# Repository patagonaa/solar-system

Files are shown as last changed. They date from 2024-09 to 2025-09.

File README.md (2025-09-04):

# Solar System

Build thread (german) at https://chaos.social/@patagona/113149877881417810

## Overview

This is sort-of build log / lessons learned of my off-grid solar system / battery backup.

Specs/Features:
- ~7.2kWh battery
- \>5kW AC out
- 5kW PV in
- 2kW AC in (with configurable power limit)

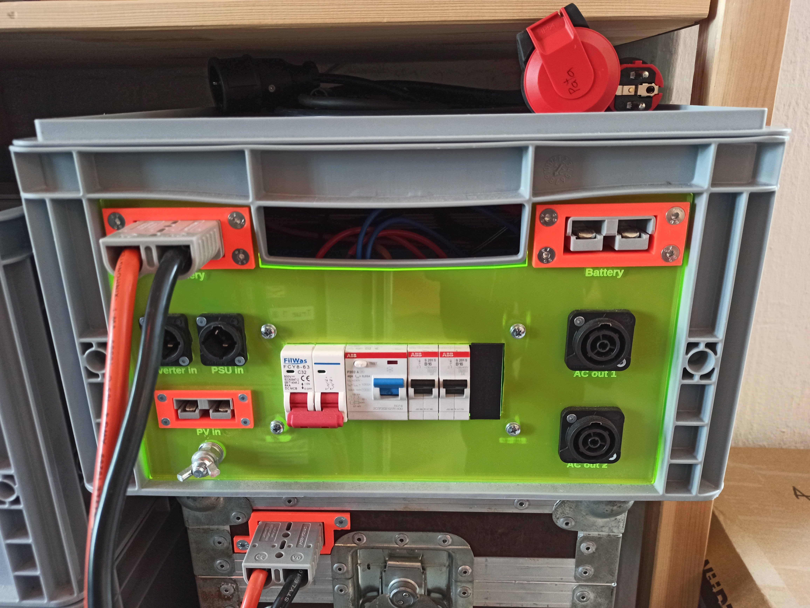
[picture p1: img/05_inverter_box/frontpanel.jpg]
Photo of the laser-cut frontpanel on the side of the euro container with all of the connectors fitted


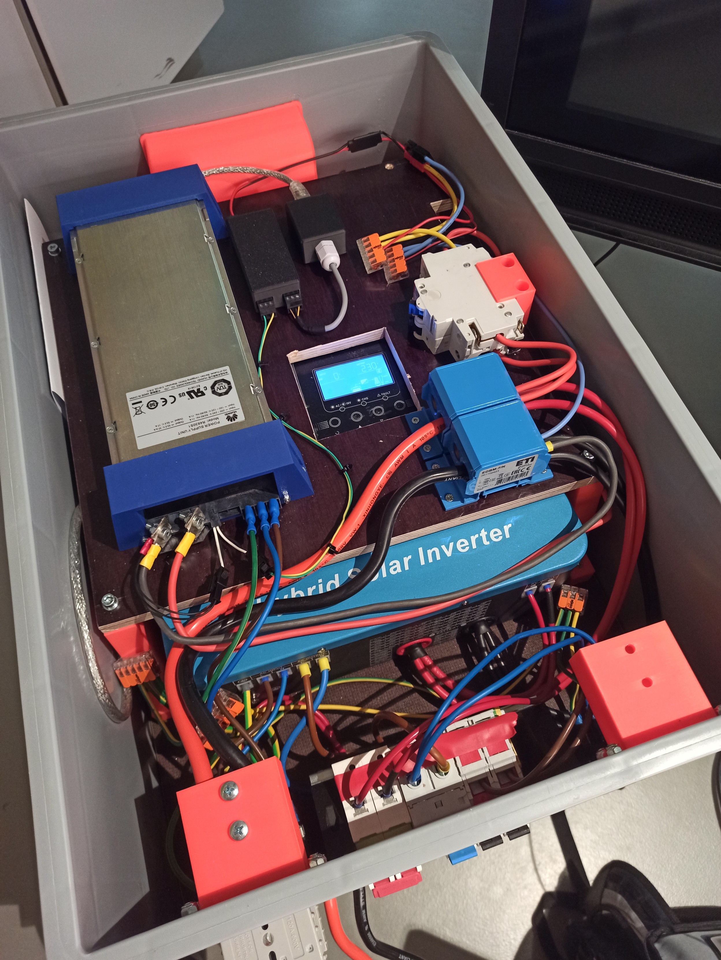
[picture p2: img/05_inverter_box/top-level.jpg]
Photo of the second level of the inverter box. A laminated board is mounted on the base plate with 3D printed spacers. The PSU, an ESP32, circuit breakers and power distribution blocks are mounted on the plate.


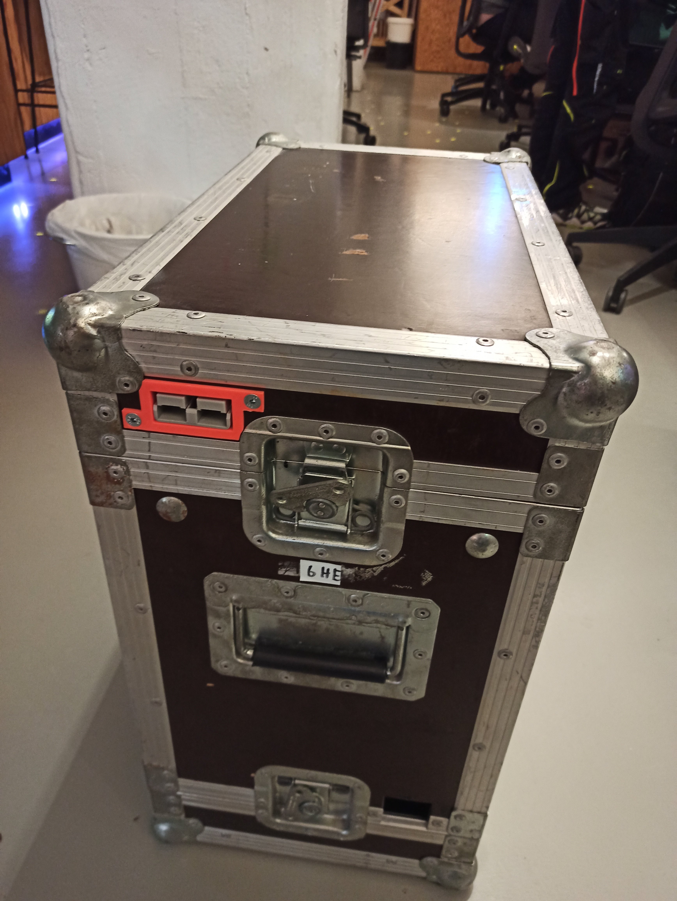
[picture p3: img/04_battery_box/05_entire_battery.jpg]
Photo of the battery. It's a black flight case with a large power connector embedded into the lid with an orange 3d printed part.


## Batteries
Basically, what drove me to start this project.

Someone was selling three Pylontech battery modules (1x US2000C, 2x US2000, each 15S LiFePo4, 2.4kWh) for really, really cheap (<25€/kWh) because they were water damaged.

So of course, I picked them up and as expected, the BMS PCBs were corroded to the point of not being feasible to repair (mostly due to the half-assed "conformal coating" applied to the PCBs), but the battery cells themselves were fine, albeit still a bit wet, limescale everywhere and a bit unbalanced.

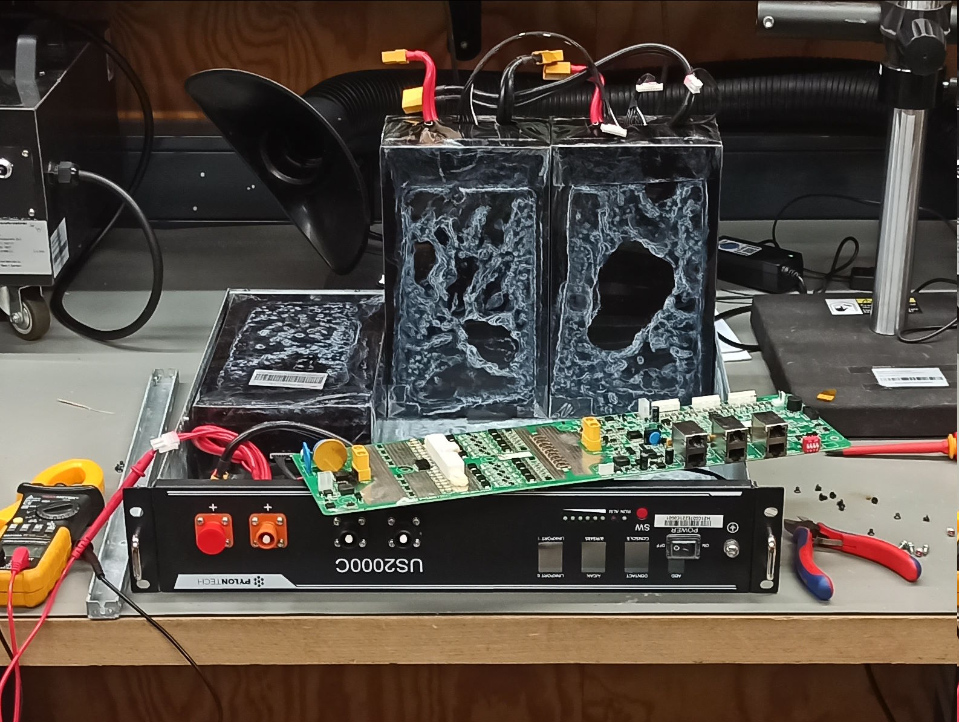
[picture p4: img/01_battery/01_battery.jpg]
picture of one opened battery pack with limescale on the cell packs and casing


After opening up the packs, letting them dry, cleaning up the limescale/corrosion and balancing them, all of the cells seem to be fine.

### BMS
To replace the corroded BMS I decided to get DALY K-Series 15S 100A "Smart" BMS modules.

If they had been available then, I'd probably have gone with the new DALY 100Balance BMS with 1A active balancing because the passive balancing of the K-Series is a bit weak for these huge cells.

#### Mount

To mount the BMS, I designed some adapter / mounting plates that fit the original mounts / standoffs of the Pylontech battery modules.

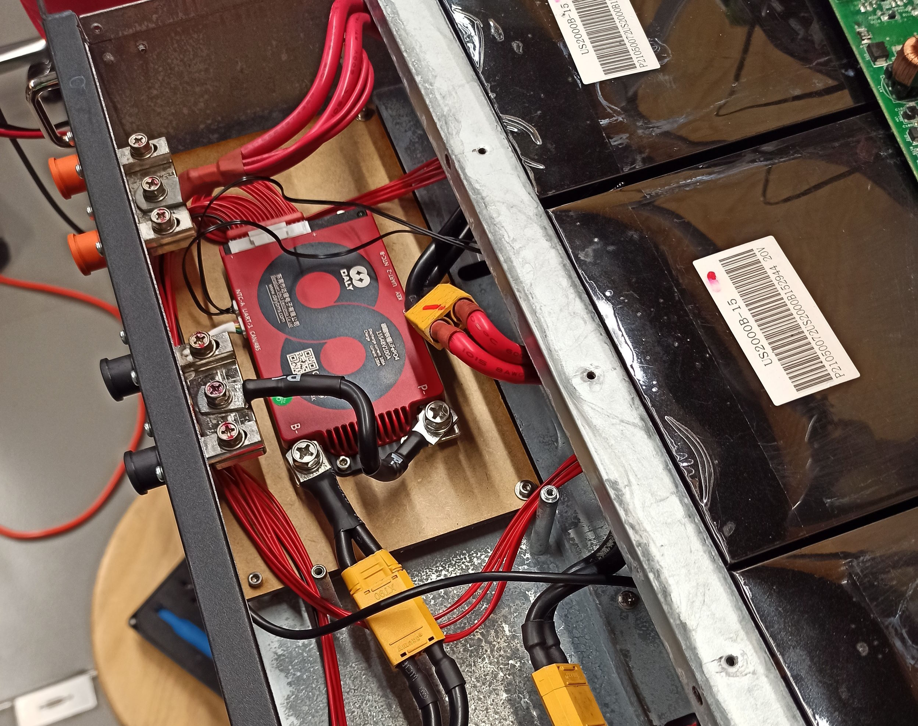
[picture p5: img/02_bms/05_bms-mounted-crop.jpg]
the BMS mounted on a laser-cut wooden board screwed to original battery case standoffs


The design files can be found in `cad/battery/bms-mount`.

#### Protocol
The BMS has a UART, RS485 and CAN interface. There is already a DALY BMS integration using a UART interface in ESPHome, however that is for the older DALY BMS, not the new H/K/M/S-Series (for which there is already a [GitHub issue](https://github.com/esphome/issues/issues/5476)).

After looking at the Windows software and the protocol documentation provided in the GitHub issue, I implemented the new protocol as an ESPHome component which I've released under [patagonaa/esphome-daly-hkms-bms](https://github.com/patagonaa/esphome-daly-hkms-bms).

### Case
For transport, the batteries are mounted in a used flight case.
I'm using an Anderson-style connector as interconnect between battery and inverter (and other loads), which I've mounted towards the outside of the case so it can be used with the lids on.

There are two parts two the mount:
one that holds the connector (`cad/battery/battery-sb120-mount/battery-connector-mount.scad`)
and one for between mount and plug so the mount doesn't get squeezed when tightening the screws (`cad/inverter-box/frontpanel/handle-filler.scad`).
The mount has later been adapted to be a lot stronger (due to not having to fit in the tight space on the lid) for the front panel (`cad/inverter-box/frontpanel/sbmount.scad`).

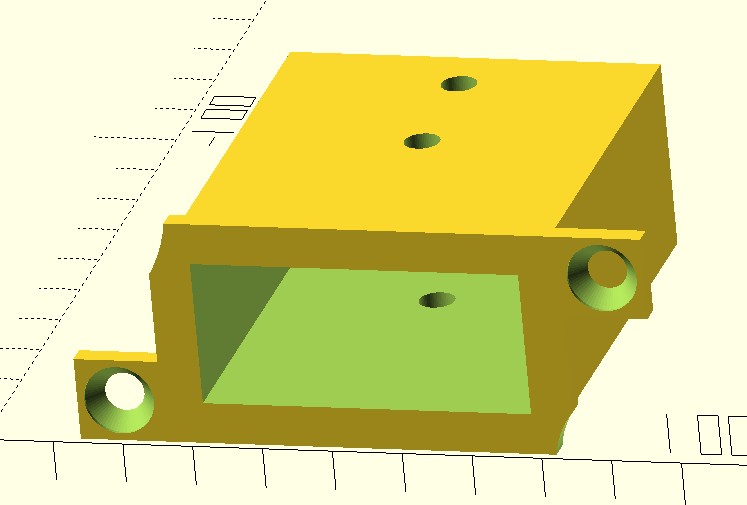
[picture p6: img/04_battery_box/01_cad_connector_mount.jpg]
screenshot of the connector mount. it's a box around the connector with flanges with countersunk holes for panel mounting

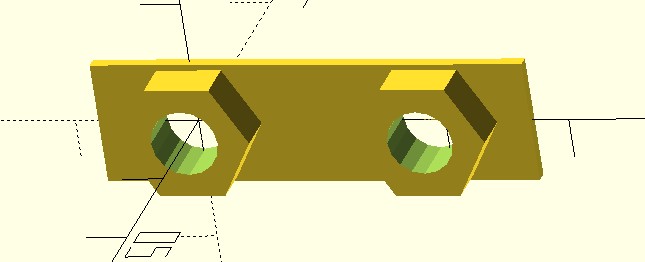
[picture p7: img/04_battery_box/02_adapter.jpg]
screenshot of a small part with two hex protrusions on a plate

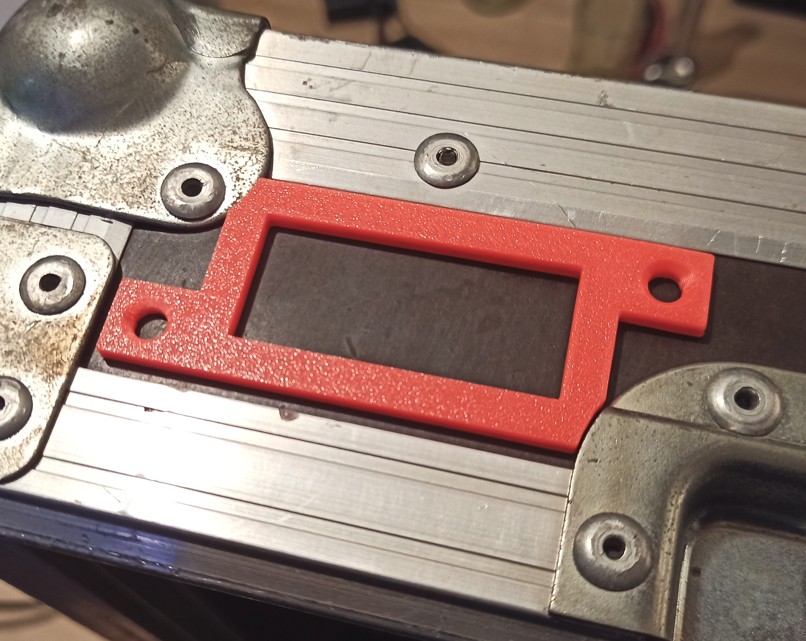
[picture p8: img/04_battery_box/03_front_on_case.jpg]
photo of the front of the mount (with the connector hole and mounting flanges) lying on the flight case. There are two round cutouts for metal parts of the flight case

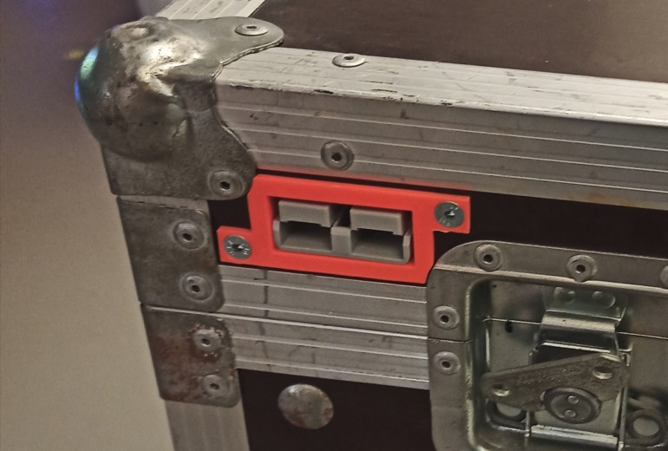
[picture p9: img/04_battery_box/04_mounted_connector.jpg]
photo of the flight case with the mounted connector

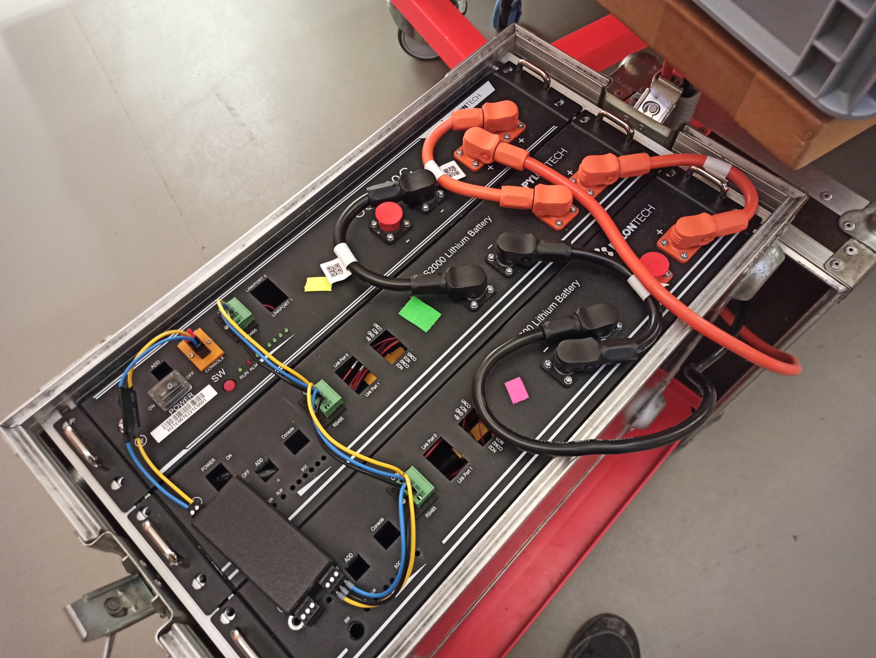
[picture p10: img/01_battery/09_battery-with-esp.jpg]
photo of the flight case with the lid open so you can see the wired up battery packs and BMS bus connections to the ESP32


## Inverter
I decided to go with a "EASun ISolar-SMH-II-7KW" (which is produced by the ODM "Voltronic", similar/equal devices are also sold under the names "MPPSolar", "PowMr", "Powland", "FSP", ...), mostly because it was cheap and has a lot of output power.

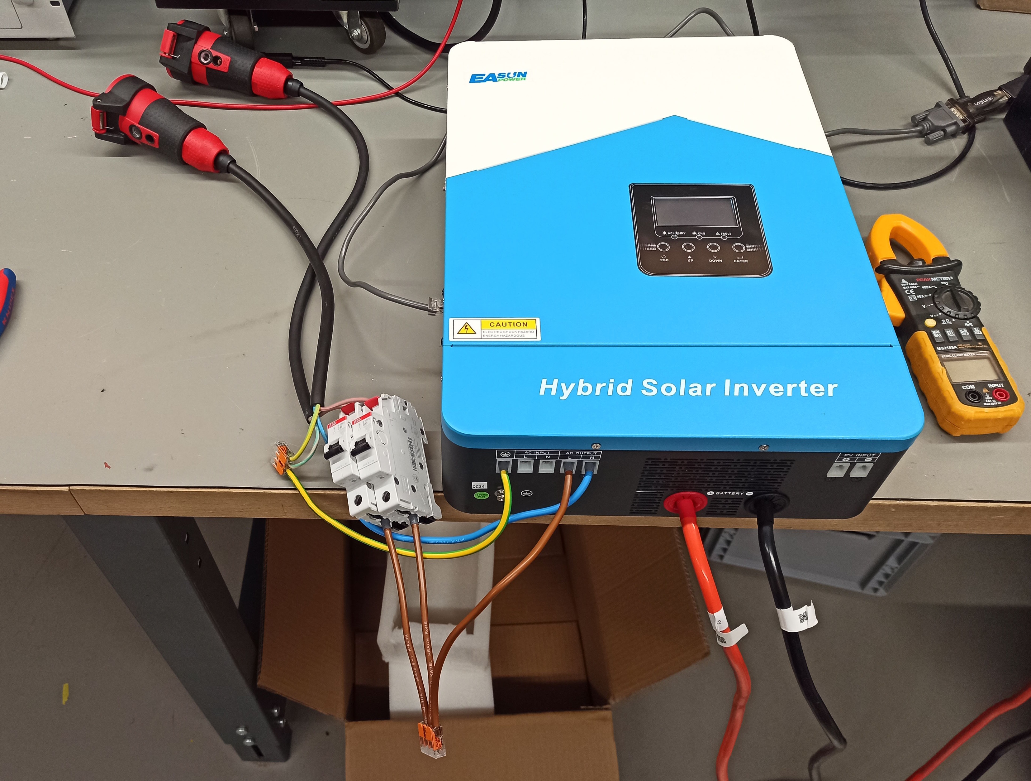
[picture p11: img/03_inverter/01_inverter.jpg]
picture of the inverter with two Schuko sockets and thick battery wires hooked up to it


It wouldn't go up to the advertised 6.2kW in my testing (it already showed 99% load at around 5.4kW), but that might be battery current limited due to the relatively low battery voltage (15S LiFe instead of 16S LiFe or lead acid, still 120A!), so in combination with the solar input or with a higher input voltage, it should go even higher.

#### Protocol

The inverter has a RS232/RS485 interface which can be used to read data from the inverter (using a custom mostly-ASCII-based protocol) and which has been implemented by several people already:

- https://github.com/jblance/mpp-solar
- https://esphome.io/components/pipsolar.html

### Inverter Box
The inverter is mounted on a plate in a 60x40x22cm euro container for easy transport and (at least minimal) water-resistance,
along with all the other necessary support hardware (circuit breakers, etc.).

Files in `cad/inverter-box/box`.

#### Front Panel
There is a laser-cut front panel exposing all the important connections (DC, AC, PV) on the short side of the euro container.

Files in `cad/inverter-box/frontpanel` (also includes the SB50/SB120 mounts, DIN rail mounts, etc.).

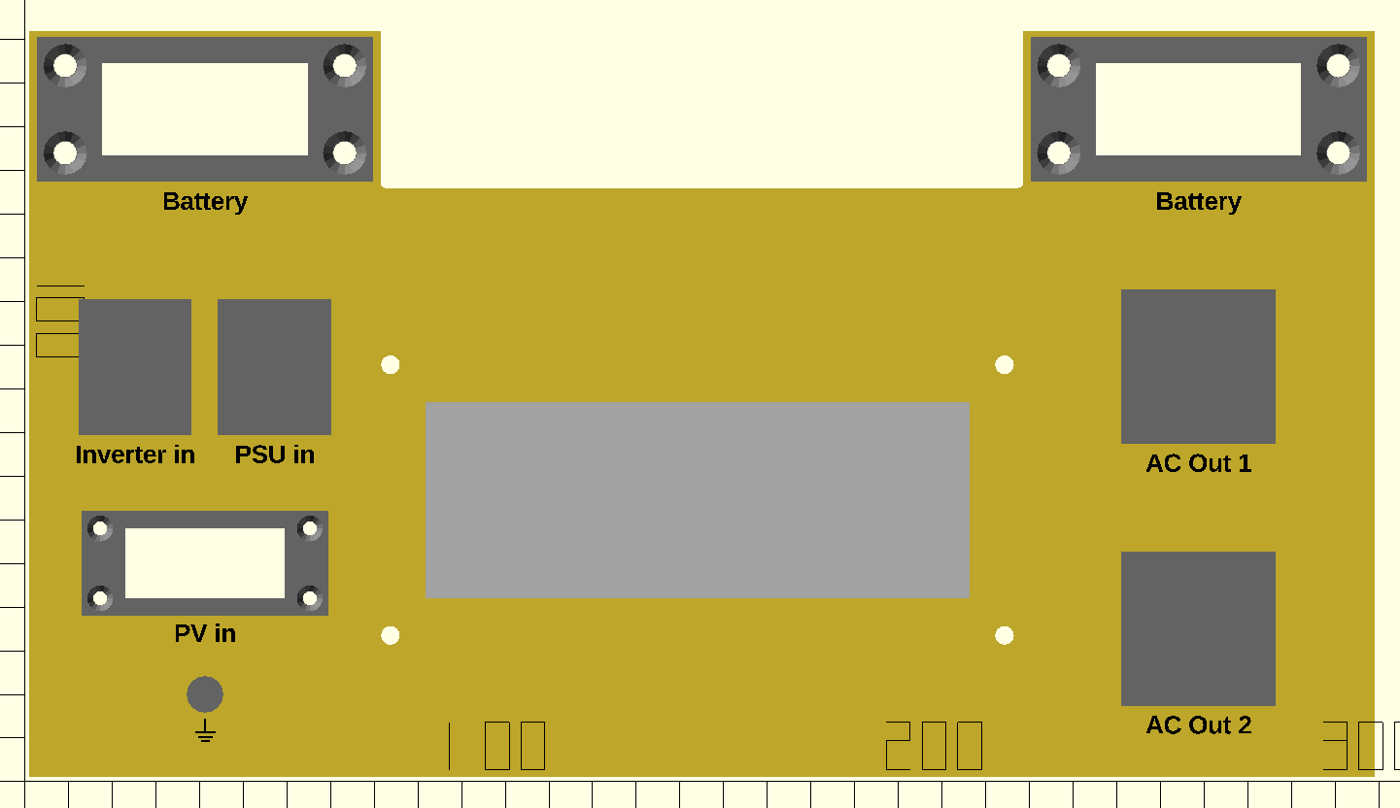
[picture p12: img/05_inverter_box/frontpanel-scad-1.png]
OpenSCAD screenshot of the front panel (see german Mastodon post for better alt text)

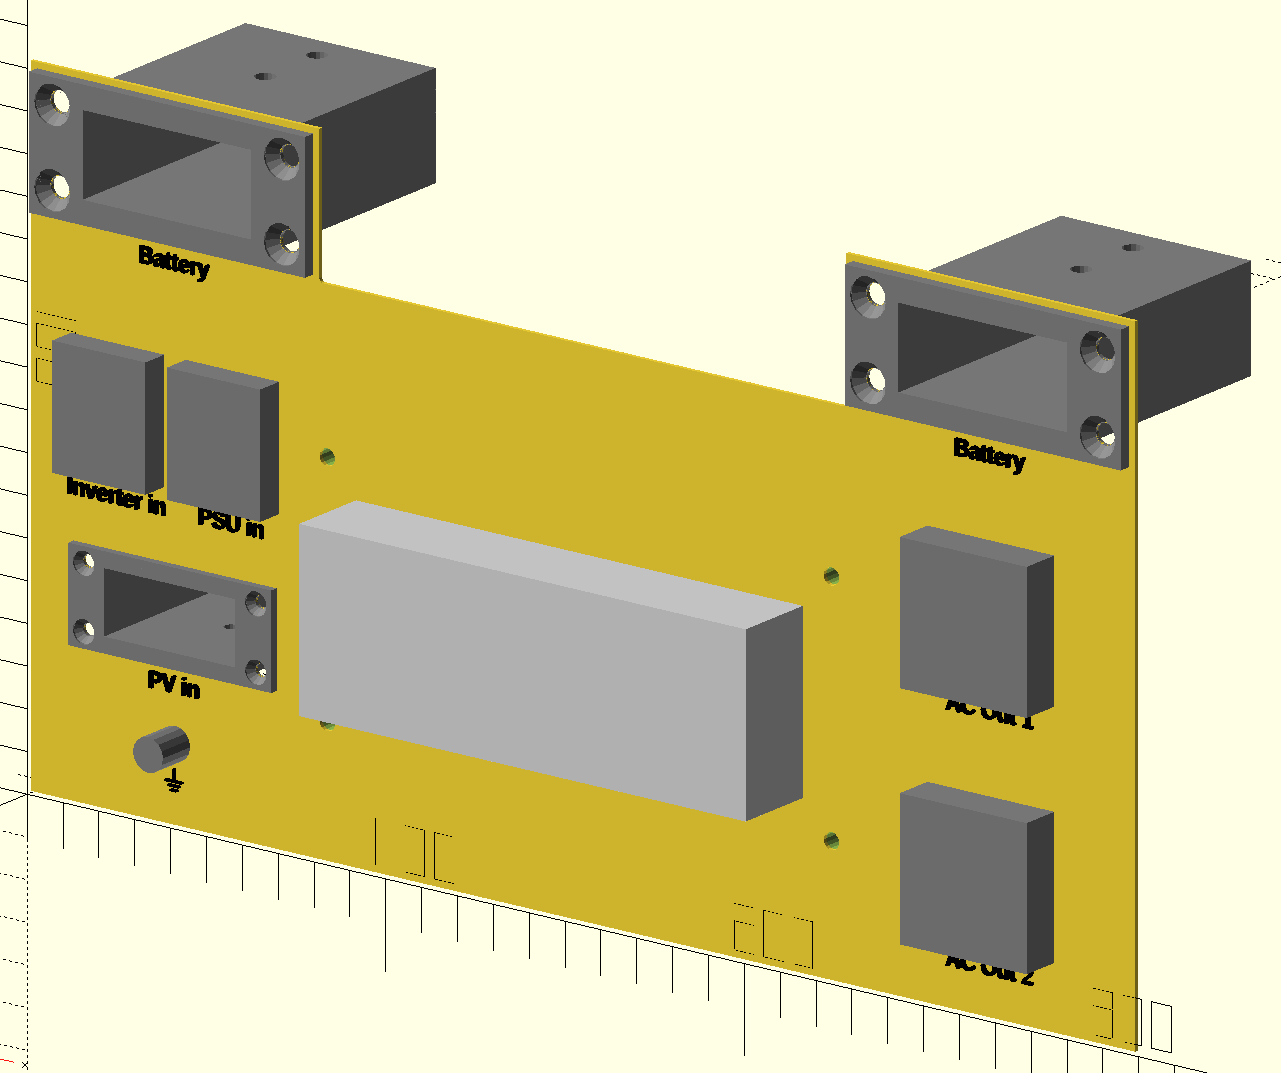
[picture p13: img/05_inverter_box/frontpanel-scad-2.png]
OpenSCAD screenshot of the front panel

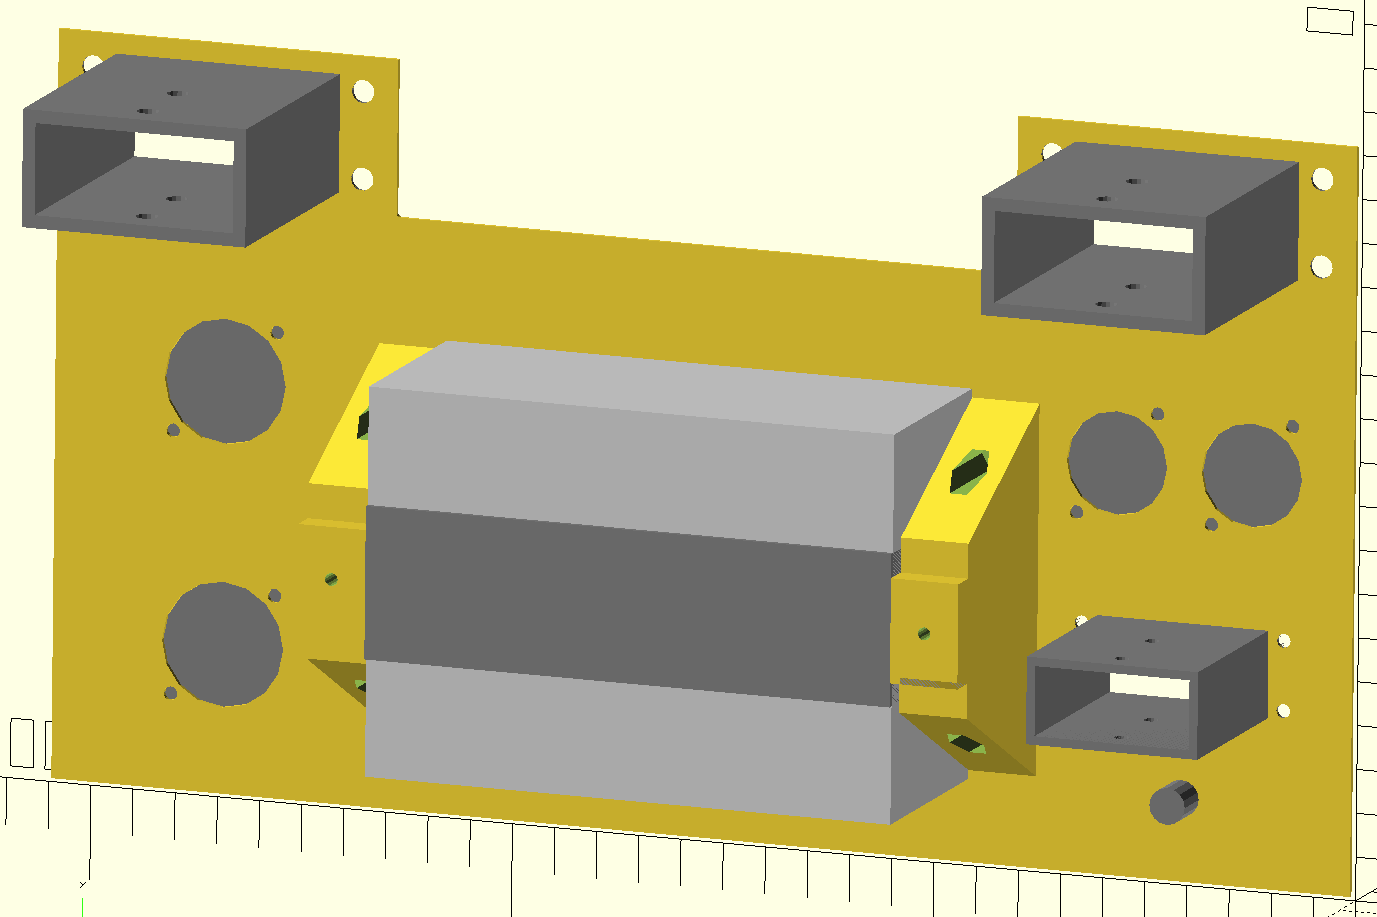
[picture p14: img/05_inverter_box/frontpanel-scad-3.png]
OpenSCAD screenshot of the front panel

Photo of the laser-cut frontpanel on the side of the euro container with all of the connectors fitted

#### Air Duct
To prevent overheating, an air duct was designed (in Fusion) and 3D printed to direct the warm air from the
inverter fans directly out the Eurobox handle.

Files in `cad/inverter-box/air-duct`.

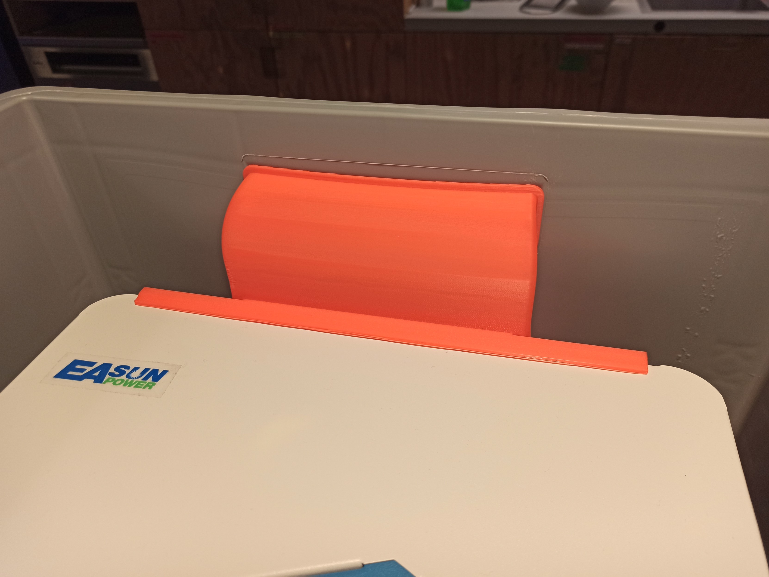
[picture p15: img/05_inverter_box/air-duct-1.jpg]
Photo of the inside of the Eurobox. Between the inverter and the Eurobox is a neon orange 3D-printed air duct that curves from the fan outlet of the inverter to the Eurobox handle.

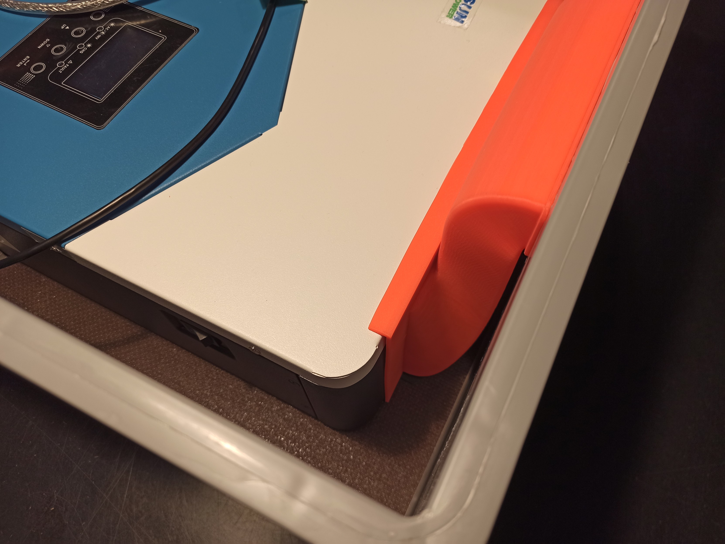
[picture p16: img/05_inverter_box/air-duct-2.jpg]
Second view, the part is positioned with an edge at the top of the inverter and also has a flat area to the left and right of the fans for better sealing.

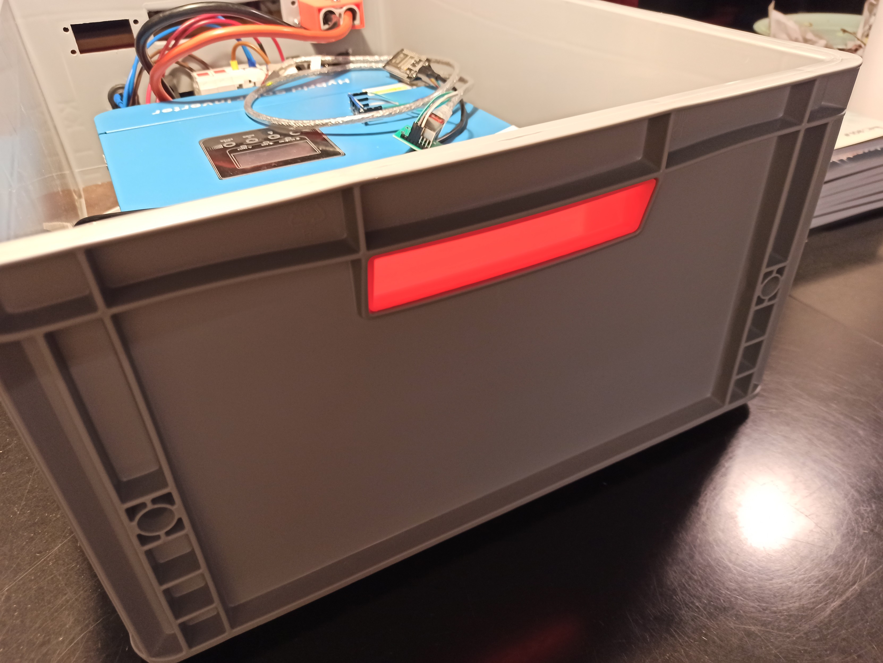
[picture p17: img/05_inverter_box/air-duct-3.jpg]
View from the outside, the orange 3D printed part fits perfectly into the Eurobox handle


## PSU
To be able to limit the AC power input (for charging the batteries with a small generator) a Huawei R4830 PSU has been added to the inverter box as well.

See my [Documentation](https://github.com/patagonaa/huawei-r48xx) and [ESPHome component](https://github.com/patagonaa/esphome-huawei-r4850) for more info about these PSUs.

For this, a second level has been added to the inverter box to hold the PSU, the necessary power distribution blocks and circuit breaker and some additional unrelated hardware (auxilary power circuit breaker, ESP32 board)

Photo of the second level of the inverter box. A laminated board is mounted on the base plate with 3D printed spacers. The PSU, an ESP32, circuit breakers and power distribution blocks are mounted on the plate.

## Misc other CAD parts
- `cad/inverter-box/frontpanel/sbmount.scad`: Panel mount for Anderson SB120 and SB50 connectors
- `cad/inverter-box/din-rail-plug/`: Part that fits into the cutout for the DIN rail parts so not each unit has to be filled
- `cad/esp-box`: Case that fits a LilyGO TTGO T-CAN485 board (with CAN bus and RS485) and an RJ45 breakout board for the inverter RS485
    - v2 splits ESP and breakout board in separate cases
- `cad/battery/battery-fpconnector-bus`: Mount for pluggable screw clamps which fits in the Battery RJ45 hole to interface with the BMS RS485
- `cad/battery/battery-fpconnector-aux-power`: Mount for an Anderson Powerpole connector which fits in the Battery RJ45 hole to power an ESP32
- `cad/lxcharger-end-cap`: End cap to replace the default barrel jack of an LXCHARGER H65AC DC-DC USB-C charger with an XT30.
- `cad/inverter-box/mcb-mount`: Part to mount din-rail miniature circuit breakers on a board sideways
- `cad/inverter-box/top-holder`: Holder to mount a board above the inverter to have make space for the PSU, power distribution blocks, etc. (printed with a pause to insert screw nut).

## You Get What You Pay For: RS485 Transceiver Modules
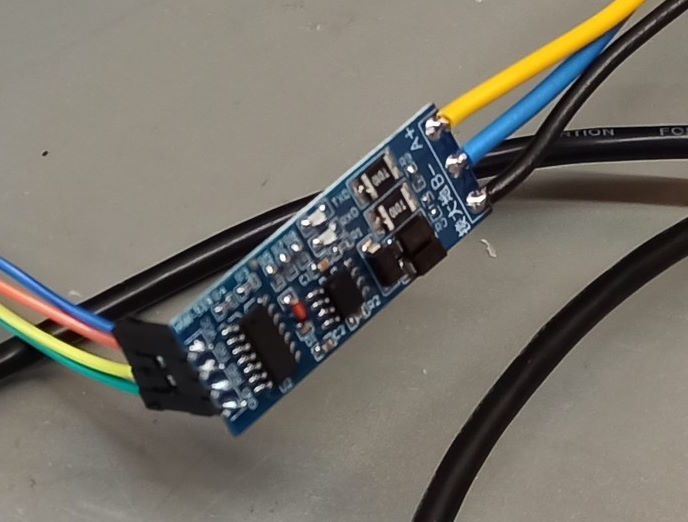
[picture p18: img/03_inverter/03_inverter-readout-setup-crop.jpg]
picture of one of the RS485 transceiver modules


The (pretty common) RS485 transceiver modules I used for inverter communication _do_ have a ground pin on the RS485 side. This does, however not mean it is actually connected to anything meaningful.

Actually, there is _no connection_ between the TTL- and RS485-side ground, which means any stray electric current flows directly into the A/B inputs of the RS485 transceiver.

In some cases (for example, when both the PV input and the MCU are ground-referenced, even just through a Y-capacitor of a PSU) there may be something like 90V AC at 700µA between the two sides of the RS485 transceiver, killing it pretty much instantly.

Running a wire from the TTL-side ground to the RS485-side ground fixes that issue by giving the stray currents a direct path to flow.

## You Get What You Pay For: Inverter

### Startup Voltage
At one point, the inverter just stopped working (when switching it on, it turned off itself after a few seconds). Turns out, there is an (undocumented) "cold start" voltage, that is hard-coded to be ~4V above the low-voltage cutoff. Means, when the low voltage cutoff is set to 45V, the inverter will just not start below ~49V.

Also, the battery voltage readout was wrong by around 0.7V, however that could be fixed through a serial command (can be sent using [mpp-solar](https://github.com/jblance/mpp-solar): `mpp-solar --porttype serial -p COM4 -c BTA+01 -I` to increase voltage reading by 50mV, can be run multiple times until the value is correct).

### Questionable Isolation, EMF
The different parts of the circuit (PV charger, battery DC-DC, AC Output) are isolated from each other, but still loosely coupled via (stray?) capacitances.

When the AC output is on, it seems like the H-bridge switching the ~350V DC bus during zero-crossing causes a short but large voltage spike (~300v) that is coupled back to the PV input and can be measured between the PV input and PE (and felt on the terminals!).  
This means, if PE is grounded, the solar panels and their wires become an antenna that radiates those pulses as EMF (probably, I didn't have anything to measure with).  
If PE is _not_ grounded, the solar panels lying on the ground make a great plate capacitor to ground, making the PE and everything hooked up there an antenna instead.

Those issues could probably be fixed / mitigated somewhat with an extra RF filter, however a 32 Amp RF filter sounds expensive.

## You Get What You Pay For: DALY BMS

### BMS Communication
The DALY BMS comes with two TTL UART ports, CAN and RS485. The DALY BMS RS485 protocol is well-documented and also implemented in ESPHome.

However, as it turns out, the new (2023?) lineup of BMS from DALY (H/K/M/S series) use another communication protocol. This new protocol is called "Modbus" internally in the PC software and looks just like regular Modbus.

After some messing around with Modbus software and not getting it to work, I figured out that _the reply from the BMS has a different device id than the request_, which makes it completely incompatible with all available Modbus software / libraries, so custom software had to be written _again_ (see [above](#protocol)).

### Current measurment
As it turns out, the BMS current measurment is messed up in several ways (see below).
This also affects the couloumb counting / state-of-charge calculation.

#### Miscalibration
At the same current, the three BMS all showed different currents (up to a few 100mA). This could be solved by doing a calibration of all of them at 0 and 10A

#### Sampling Rate
The current measurement sample rate seems pretty low and there also seems to be no averaging at all. This means, when the AC inverter is on and pulls e.g. 10A RMS (as 50Hz sinusoidal half-waves), when polling the current every second, the readings may be 2 -> 12 -> 5 -> 1, instead of just showing a constant 10A.

#### High Dead Zone / Low accuracy ADC
The BMS simply does not measure anything below 100mA. When the inverter is off and there is just a small load from the ESPs etc., the BMS will just not measure anything.

## You Get What You Pay For: LilyGO T-CAN485
Again, how hard could it be to do RS485? (answer: apparently very hard)

They use an MAX13487E transceiver, which has "AutoDirection Control", which means instead of driving the bus in both directions, resulting in in [0.4V, 5V, -5V] (idle, mark, space - with proper termination and bias), it only drives it in one direction, relying on the bias for the other direction, resulting in [0.4V, 0.4V, -5V]. This isn't great interfereence-wise, but it works and is spec-compliant.

However, LilyGO chose to terminate the bus with 120Ω and bias it with 4.7kΩ, resulting in the voltages [0.06V, 0.06V, -5V], which just barely may or may not work. They could've omitted the termination, done the biasing right _or_ just use a "normal" transceiver (they have enough GPIOs to do so), but it seems they've instead chosen the perfect combination of parts to make it not work 🤦.

Additionally, they also did the same as [#1: Transceiver Modules](#you-get-what-you-pay-for-rs485-transceiver-modules), so the protection circuitry doesn't really protect the transceiver as the protection ground isn't hooked up to the transceiver ground (besides a weak connection through 1MΩ + 1nF).

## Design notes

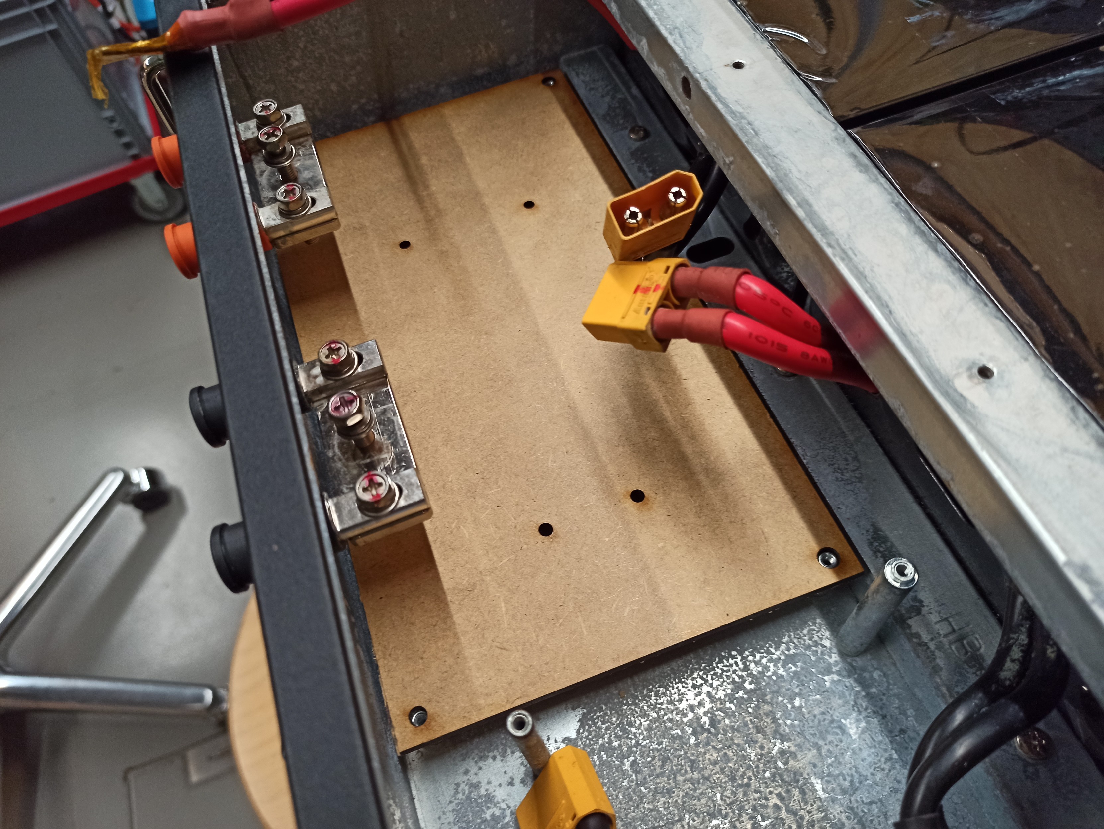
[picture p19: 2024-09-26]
img/02_bms/03_bms-plate.jpg

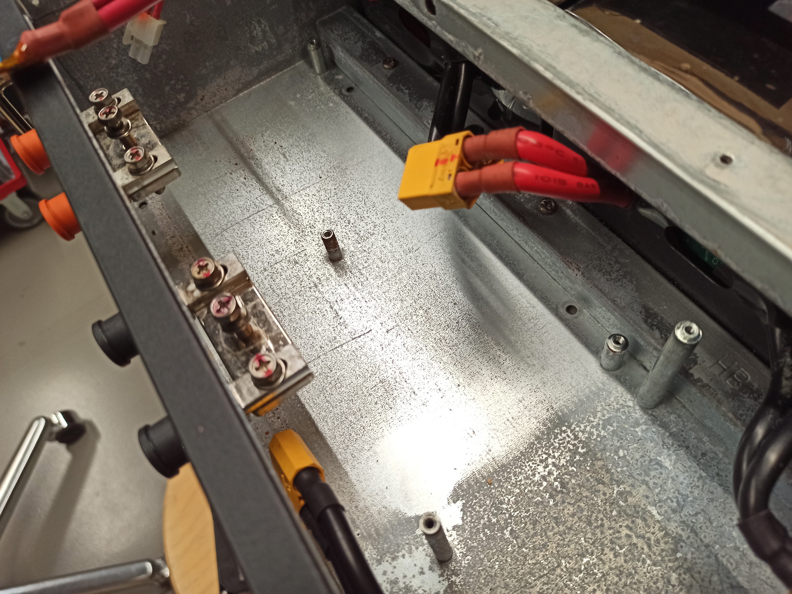
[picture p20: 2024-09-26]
img/02_bms/02_bms-spot.jpg

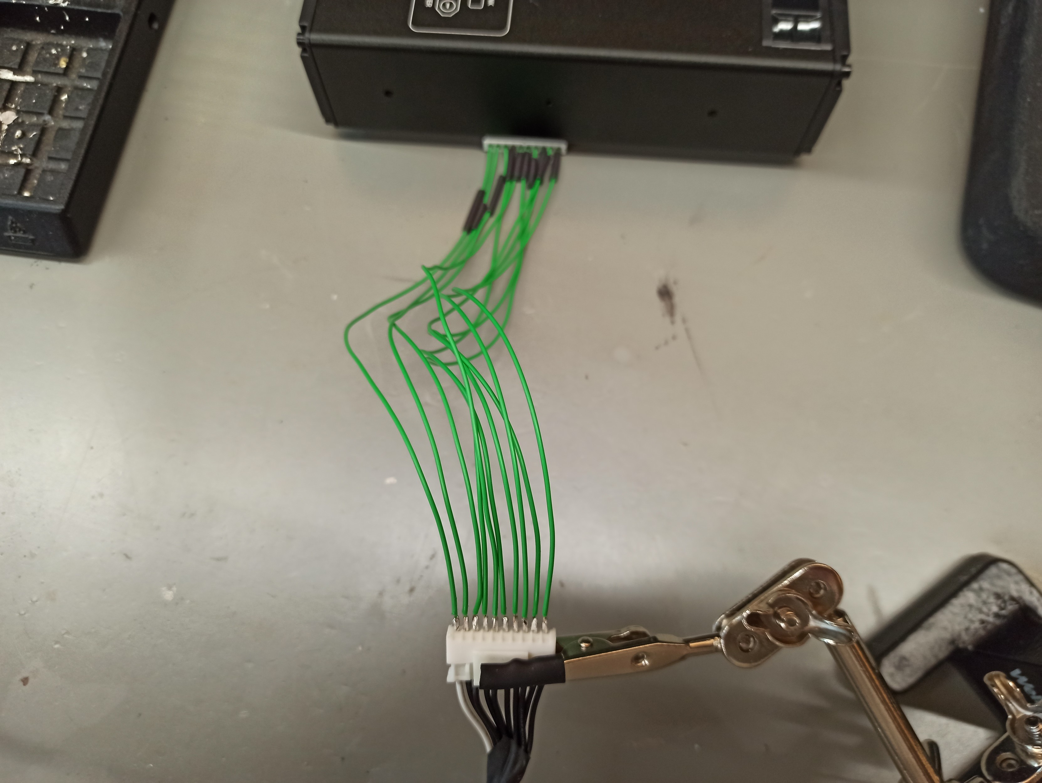
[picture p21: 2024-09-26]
img/01_battery/06_battery-charging.jpg

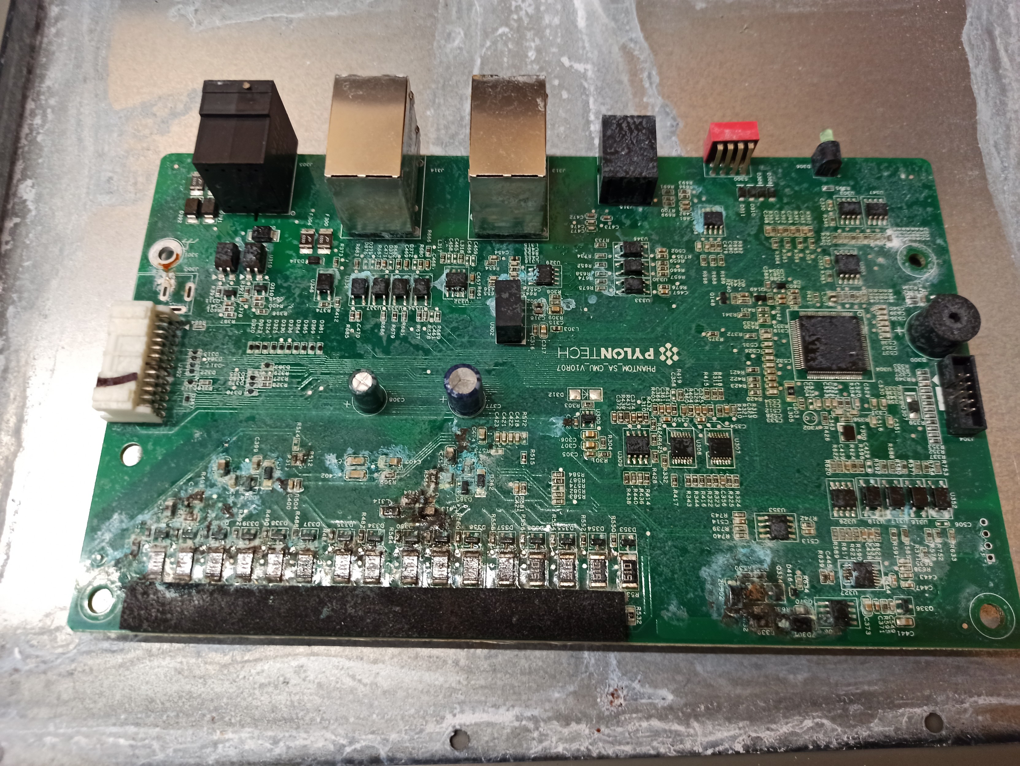
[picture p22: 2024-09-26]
img/01_battery/03_bms-corroded.jpg

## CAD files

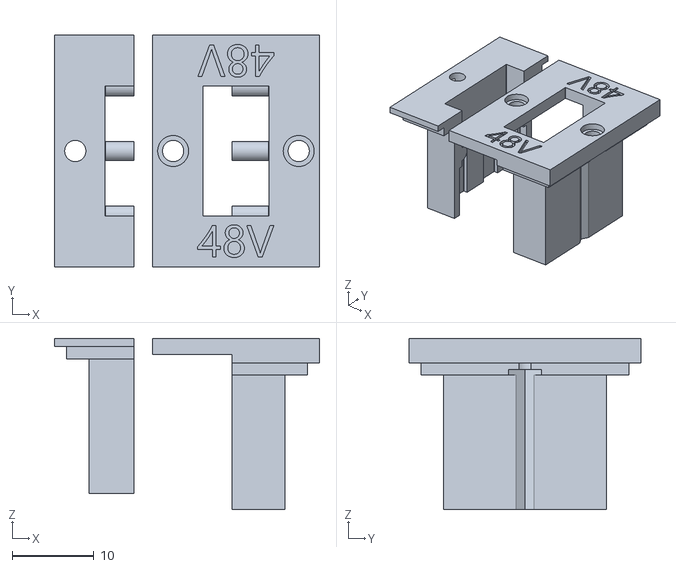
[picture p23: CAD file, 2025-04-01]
cad/battery/battery-fpconnector-aux-power/battery-aux-power-mount.stl
32.5 x 28.5 x 21.0

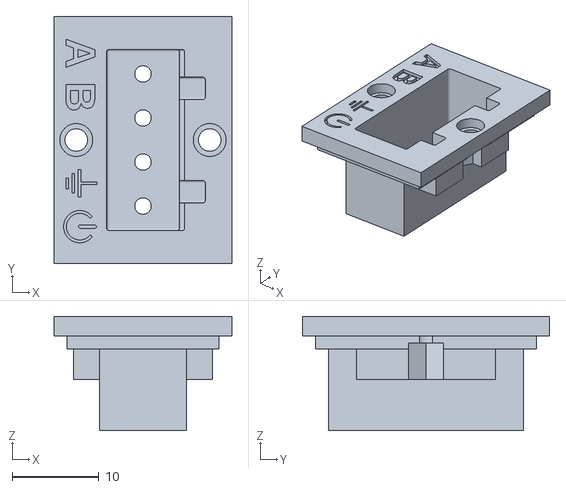
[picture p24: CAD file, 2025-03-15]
cad/battery/battery-fpconnector-bus/battery-bus-mount.stl
20.5 x 28.5 x 13.2

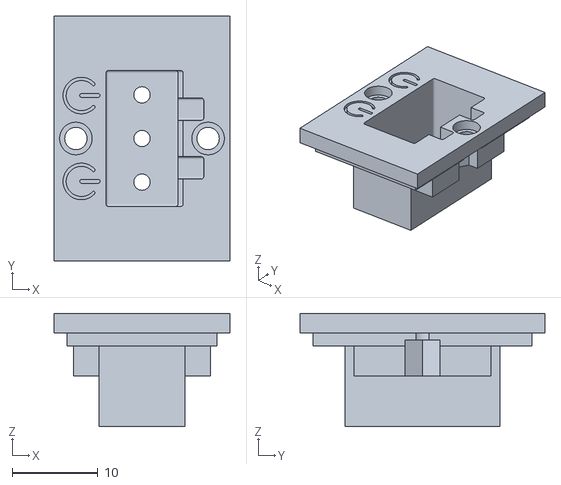
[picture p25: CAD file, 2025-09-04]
cad/battery/battery-fpconnector-switch/battery-switch-mount.stl
20.5 x 28.5 x 13.2

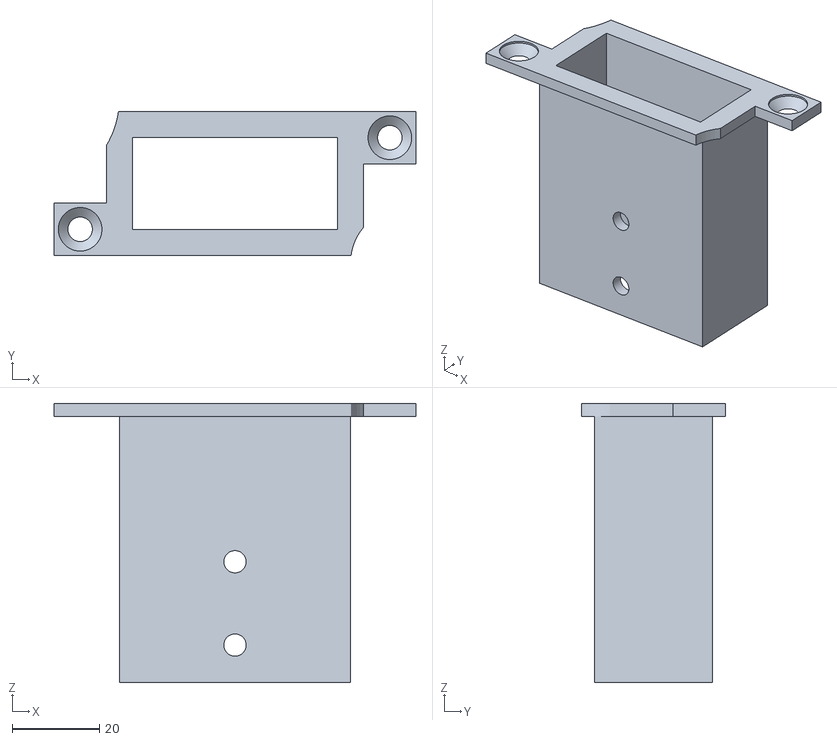
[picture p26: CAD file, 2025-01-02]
cad/battery/battery-sb120-mount/battery-connector-mount.stl
83.0 x 33.0 x 64.0

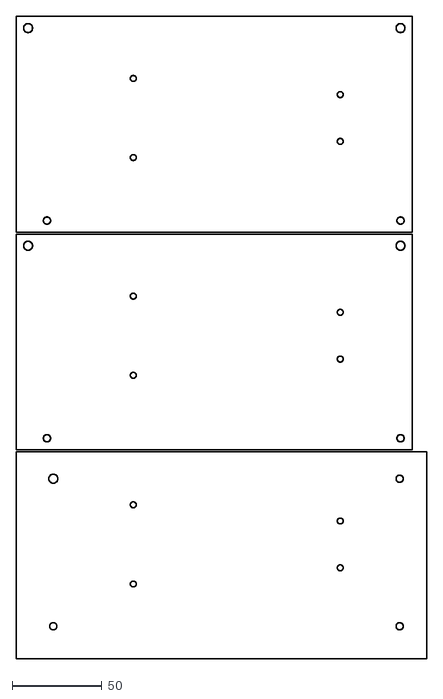
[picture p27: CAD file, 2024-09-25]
cad/battery/bms-mount/bms-mount.dxf
228.0 x 357.0

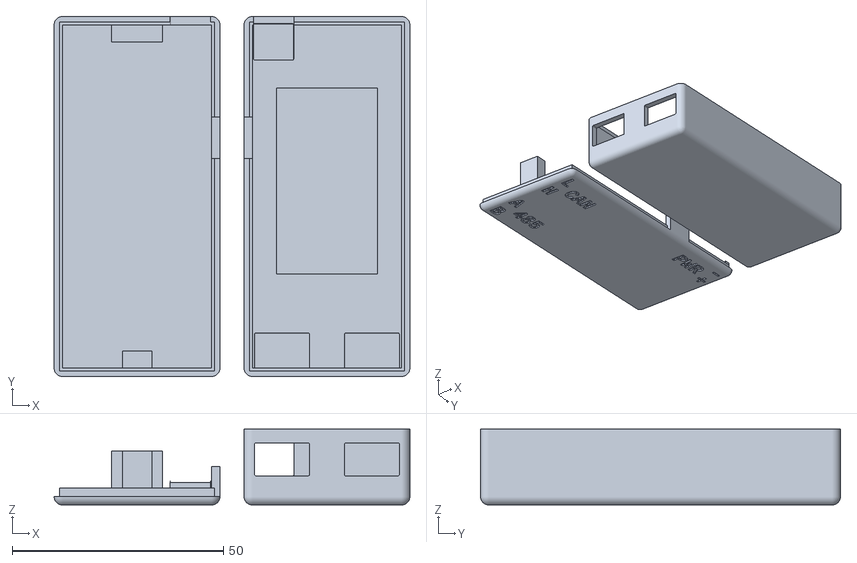
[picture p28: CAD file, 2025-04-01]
cad/esp-box/esp32-case-v2.stl
84.3 x 85.3 x 18.0

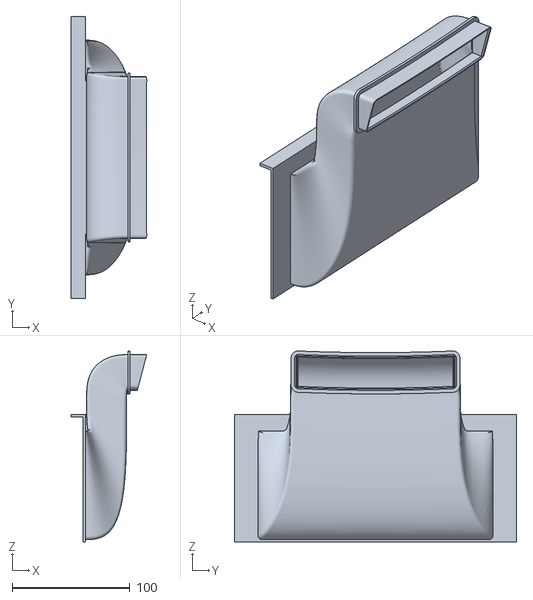
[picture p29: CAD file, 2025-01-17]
cad/inverter-box/air-duct/Duct.stl
64.0 x 239.0 x 161.9

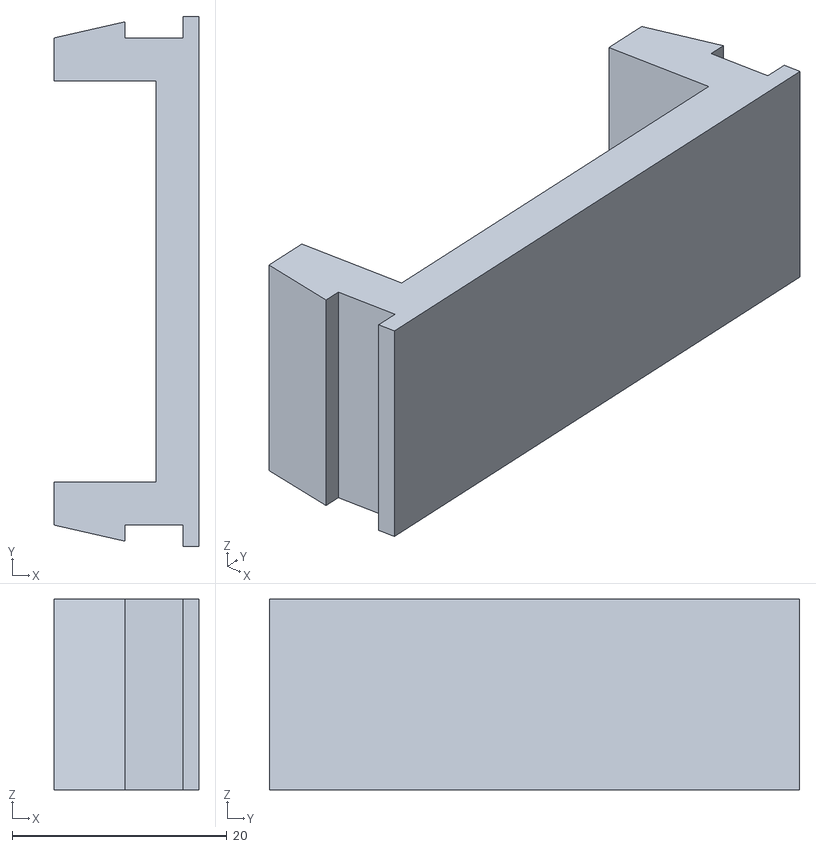
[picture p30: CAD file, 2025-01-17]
cad/inverter-box/din-rail-plug/din-rail-plug.stl
13.5 x 49.4 x 17.8

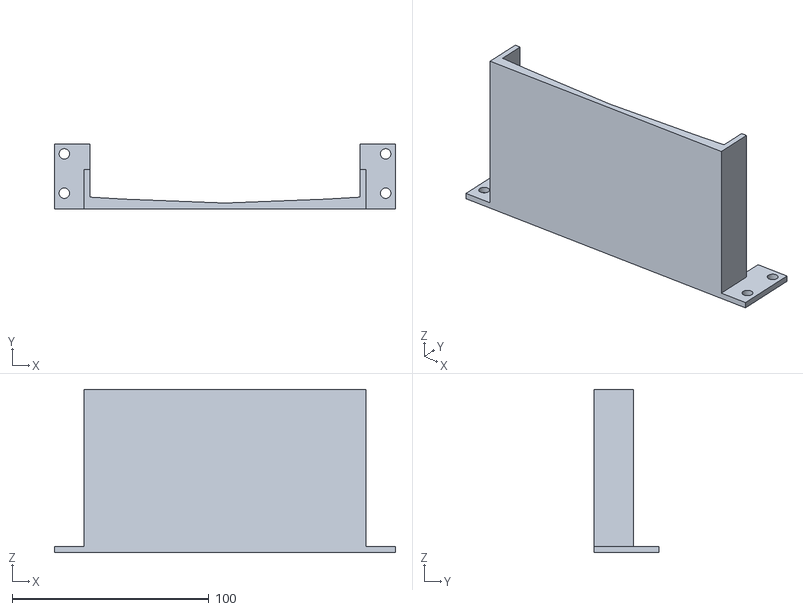
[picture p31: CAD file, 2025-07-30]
cad/inverter-box/frontpanel/handle-filler.stl
173.5 x 33.0 x 83.0

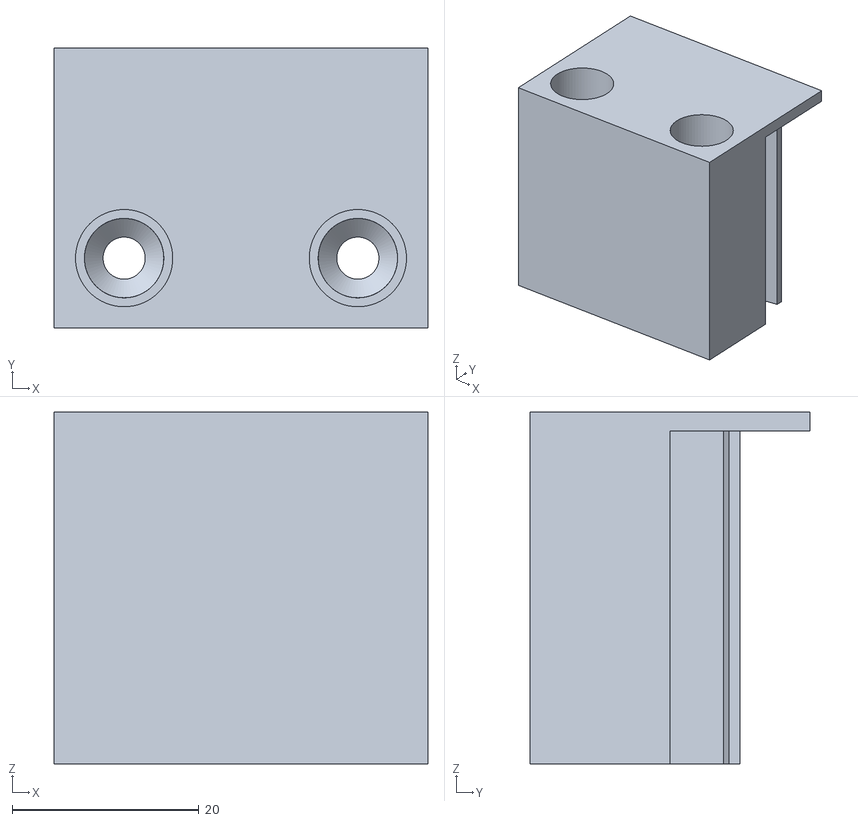
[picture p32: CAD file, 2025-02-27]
cad/inverter-box/mcb-mount/mcb-mount.stl
40.0 x 30.0 x 37.6

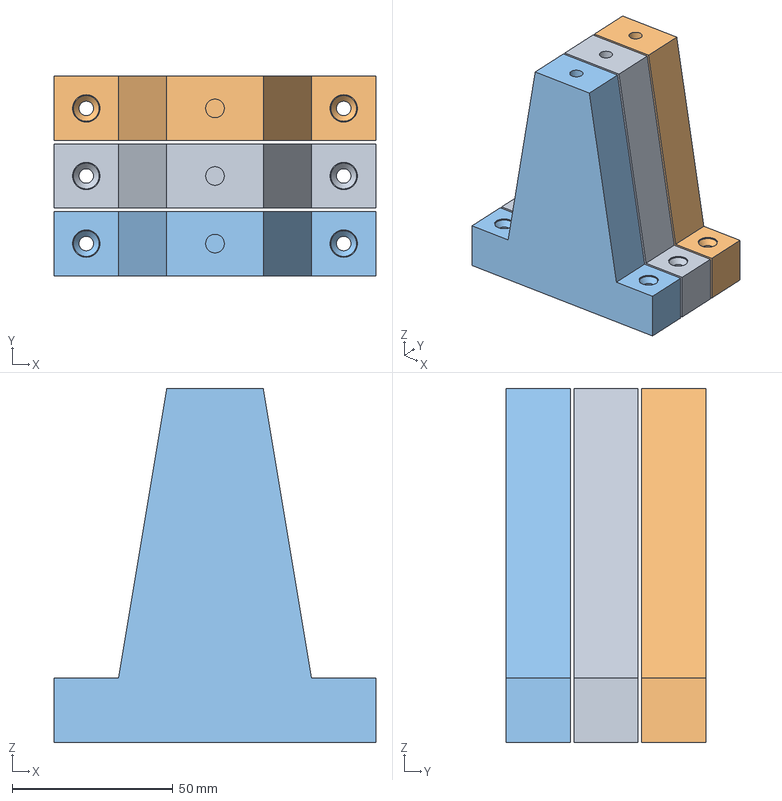
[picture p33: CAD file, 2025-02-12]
cad/inverter-box/top-holder/top-holder.3mf
100.0 x 62.0 x 110.0 mm
top-holder.stl x 3

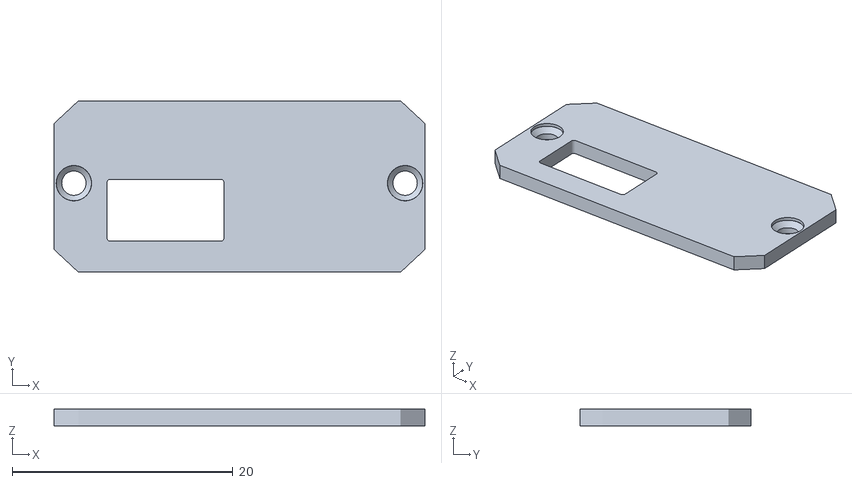
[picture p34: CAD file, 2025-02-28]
cad/lxcharger-end-cap/lxcharger-end-cap.stl
33.6 x 15.5 x 1.50

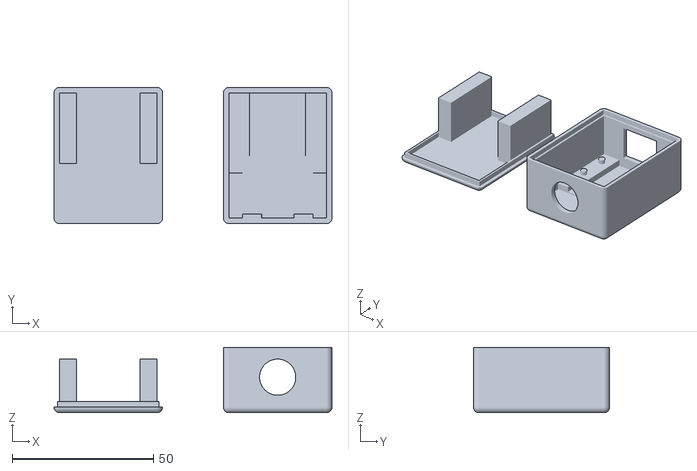
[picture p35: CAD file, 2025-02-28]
cad/esp-box/rj45-case.stl
98.5 x 48.3 x 23.2

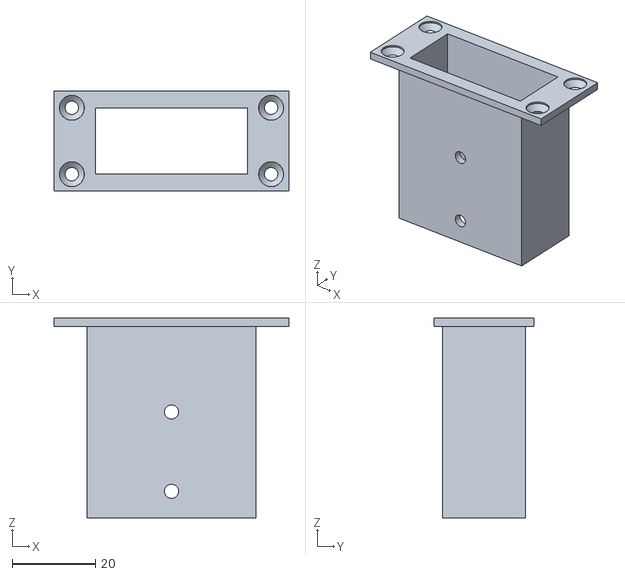
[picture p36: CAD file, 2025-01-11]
cad/inverter-box/frontpanel/mount_sb50.stl
56.6 x 24.0 x 48.1

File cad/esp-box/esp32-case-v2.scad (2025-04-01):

$fn = $preview ? 16 : 64;

// V2 gedruckt am 27.02.2025
// V2.1:
// - USB-C-Position noch bisschen korrigiert
// - Position der Buchsen gefixt (fangen auf Oberseite vom Board an, nicht Unterseite)
// - Gesamthöhe reduziert (war für die Ethernet-Buchse so hoch)
// V2.2:
// - Beschriftung

tolerance = 0.3;

ttgo485Size = [35+tolerance, 81+tolerance];
ttgo485BoardThickness = 1.2;
ttgo485BoardTopMaxThickness = 3.3;
ttgo485BoardBottomMaxThickness = 2.5;

usbCSize = [7.4 + 10, 9.5+tolerance, 3.4+tolerance];
usbCPosY = 22-tolerance/2;
usbCPosX = 5.5;

connectorPins = 2.2;
connectorExtraLength = 3;

powerConnectorSize = [9, 9.2 + connectorExtraLength, 7.2];
powerConnectorPos = [9.5, 5 + connectorExtraLength, 0];

dataConnectorSize = [12.4, 9.2 + connectorExtraLength, 7.2];
dataConnectorPos = [13.2, 5 + connectorExtraLength, 0];

module ttgo485()
{
    translate([-ttgo485Size.x/2, -ttgo485Size.y, -ttgo485BoardThickness])
        cube([ttgo485Size.x, ttgo485Size.y, ttgo485BoardThickness]);
        
    translate([-ttgo485Size.x/2 - powerConnectorSize.x + powerConnectorPos.x, -powerConnectorPos.y, powerConnectorPos.z])
        color("grey")
        minkowski()
        {
            union(){
                cube(powerConnectorSize);
                translate([0,0,-connectorPins - ttgo485BoardThickness])
                    cube([powerConnectorSize.x, powerConnectorPos.y, connectorPins + ttgo485BoardThickness]);
            }
            sphere(tolerance);
        }

    translate([ttgo485Size.x/2 - dataConnectorPos.x, -ttgo485Size.y - dataConnectorSize.y +dataConnectorPos.y, dataConnectorPos.z])
        color("grey")
        minkowski()
        {
            union(){
                cube(dataConnectorSize);
                translate([0,dataConnectorSize.y - dataConnectorPos.y,-connectorPins - ttgo485BoardThickness])
                    cube([dataConnectorSize.x, dataConnectorPos.y, connectorPins + ttgo485BoardThickness]);
            }
            sphere(tolerance);
        }
    
    translate([-ttgo485Size.x/2 + dataConnectorPos.x - dataConnectorSize.x, -ttgo485Size.y - dataConnectorSize.y +dataConnectorPos.y, dataConnectorPos.z])
        color("grey")
        minkowski()
        {
            union(){
                cube(dataConnectorSize);
                translate([0,dataConnectorSize.y - dataConnectorPos.y,-connectorPins - ttgo485BoardThickness])
                    cube([dataConnectorSize.x, dataConnectorPos.y, connectorPins + ttgo485BoardThickness]);
            }
            sphere(tolerance);
        }
    
    sdCutoutSize = [24, 44, 2.5];
    
    translate([-sdCutoutSize.x/2,-sdCutoutSize.y - 15,-sdCutoutSize.z-ttgo485BoardThickness])
        color("grey")
        cube(sdCutoutSize);
        
    translate([-ttgo485Size.x/2 - usbCSize.x + usbCPosX,-usbCSize.y + -usbCPosY, 0])
        color("grey")
        cube(usbCSize);
}

moduleDistance = 20;

boardPosZ = 4;

caseSize = [ttgo485Size.x, ttgo485Size.y, 16];
caseThickness = 2;
module case()
{
    //ttgo485cutout
    
    ttgo485Holder1Width = 12;
    ttgo485Holder1Thickness = 4;
    
    ttgo485Holder2Width = 7;
    ttgo485Holder2Thickness = 4;
    
    ttgo485TextDepth = 0.5;
    
    
    difference()
    {
        union()
        {
            difference()
            {
            translate([-caseSize.x/2, 0, 0])
                minkowski()
                {
                    cube(caseSize);
                    sphere(caseThickness);
                }
            translate([-caseSize.x/2, 0, boardPosZ])
                cube([caseSize.x, caseSize.y, caseSize.z - boardPosZ]);
            }
            translate([-ttgo485Holder1Width/2, ttgo485Size.y-ttgo485Holder1Thickness, boardPosZ])
                cube([ttgo485Holder1Width, ttgo485Holder1Thickness, caseSize.z - boardPosZ]);
            translate([-ttgo485Holder2Width/2, 0, boardPosZ])
                cube([ttgo485Holder2Width, ttgo485Holder2Thickness, caseSize.z - boardPosZ]);
        }

        translate([0, ttgo485Size.y, boardPosZ + ttgo485BoardThickness])
            ttgo485();
            
        translate([
            caseSize.x/2 - dataConnectorPos.x + dataConnectorSize.x/2,
            0,
            caseSize.z + caseThickness - ttgo485TextDepth])
        {
            translate([-4,0.5,0])
                rotate([0,0,90])
                linear_extrude(ttgo485TextDepth + 0.01)
                {
                    text("A", font="Liberation Mono:bold", size=5, halign="left", valign="center");
                }
            translate([0,7,0])
                rotate([0,0,90])
                linear_extrude(ttgo485TextDepth + 0.01)
                {
                    text("485", font="Liberation Mono:bold", size=5, halign="left", valign="center");
                }
            translate([4,0.5,0])
                rotate([0,0,90])
                linear_extrude(ttgo485TextDepth + 0.01)
                {
                    text("B", font="Liberation Mono:bold", size=5, halign="left", valign="center");
                }
        }
        translate([
            -caseSize.x/2 + dataConnectorPos.x - dataConnectorSize.x/2,
            0,
            caseSize.z + caseThickness - ttgo485TextDepth])
        {
            translate([-4,0.5,0])
                rotate([0,0,90])
                linear_extrude(ttgo485TextDepth + 0.01)
                {
                    text("L", font="Liberation Mono:bold", size=5, halign="left", valign="center");
                }
            translate([0,7,0])
                rotate([0,0,90])
                linear_extrude(ttgo485TextDepth + 0.01)
                {
                    text("CAN", font="Liberation Mono:bold", size=5, halign="left", valign="center");
                }
            translate([4,0.5,0])
                rotate([0,0,90])
                linear_extrude(ttgo485TextDepth + 0.01)
                {
                    text("H", font="Liberation Mono:bold", size=5, halign="left", valign="center");
                }
        }
        translate([
            -caseSize.x/2 + powerConnectorPos.x - powerConnectorSize.x/2,
            caseSize.y,
            caseSize.z + caseThickness - ttgo485TextDepth])
        {
            translate([-3,-0.5,0])
                rotate([0,0,90])
                linear_extrude(ttgo485TextDepth + 0.01)
                {
                    text("–", font="Liberation Mono:bold", size=5, halign="right", valign="center");
                }
            translate([0,-7,0])
                rotate([0,0,90])
                linear_extrude(ttgo485TextDepth + 0.01)
                {
                    text("PWR", font="Liberation Mono:bold", size=5, halign="right", valign="center");
                }
            translate([3,-0.5,0])
                rotate([0,0,90])
                linear_extrude(ttgo485TextDepth + 0.01)
                {
                    text("+", font="Liberation Mono:bold", size=5, halign="right", valign="center");
                }
        }
    }
}

module diffPart()
{
    diffPartWidth = caseSize.x + caseThickness*2;
    diffPartLength = caseSize.y + caseThickness*2;
    
    innerEdge = 1.5;
    
    diffPartInnerWidth = caseSize.x + innerEdge;
    diffPartInnerLength = caseSize.y + innerEdge;
    
    translate([-diffPartWidth/2,-caseThickness,caseSize.z])
        cube([diffPartWidth, diffPartLength, 5]);

    translate([-ttgo485Size.x/2 - powerConnectorSize.x + powerConnectorPos.x, caseSize.y-powerConnectorPos.y, boardPosZ + ttgo485BoardThickness + powerConnectorPos.z])
        minkowski()
        {
            cube([powerConnectorSize.x, powerConnectorSize.y, 25]);
            sphere(tolerance);
        }
    
    translate([-diffPartInnerWidth/2,-innerEdge/2,caseSize.z - 2])
        cube([diffPartInnerWidth, diffPartInnerLength, 5]);
    
    translate([-caseSize.x/2,0,boardPosZ + ttgo485BoardThickness])
        cube([caseSize.x, ttgo485Size.y, caseSize.z]);
    
    translate([-ttgo485Size.x/2 - usbCSize.x + usbCPosX, ttgo485Size.y -usbCSize.y + -usbCPosY + 0.01, boardPosZ + ttgo485BoardThickness+0.01])
        cube([usbCSize.x, usbCSize.y -0.02, caseSize.z]);
}

if($preview){
    difference()
    {
        case();
//        translate([-12, -5, caseSize.z - 5])
//            cube(caseSize*2);
    }
    translate([50,0,0])
        color("red", 1)
        diffPart();
}

difference()
{
    case();
    diffPart();
}


translate([-45, 0, caseSize.z])
    rotate([180,0,180])
    intersection()
    {
        case();
        diffPart();
    }

//diffPart();

if($preview)
{
    translate([0, ttgo485Size.y, boardPosZ + ttgo485BoardThickness])
        ttgo485();

    translate([80, 0, 0])
        ttgo485();
}

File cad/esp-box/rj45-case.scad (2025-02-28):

$fn = $preview ? 16 : 64;

tolerance = 0.3;

rj45boardSize = [34.2+tolerance, 28+tolerance, 1.3+tolerance];
rj45holeDiameter = 2.8 - tolerance;
rj45holeWidthDistance = 28;
rj45hole1FrontPosition = -5.5;
rj45hole2FrontPosition = -16.5;

rj45PinsSize = [25, 6, 2];
rj45PinsExtraSize = 4;

module rj45breakout()
{
    rj45jackCutout = 5;
    rj45jackSize = [15.8, 18.3 + rj45jackCutout, 13.0];
    rj45jackBottomDepth = 2.5;
    rj45jackBottomExtraWidth = 4;
    
    difference()
    {
        union()
        {
        translate([-rj45boardSize.x/2, -rj45boardSize.y, -rj45boardSize.z])
            cube(rj45boardSize);
        translate([-rj45jackSize.x/2, -rj45jackSize.y + rj45jackCutout, 0])
            color("grey")
            cube(rj45jackSize);
        translate([-rj45jackSize.x/2 - rj45jackBottomExtraWidth/2, -rj45jackSize.y, -rj45boardSize.z-rj45jackBottomDepth+0.01])
            color("grey")
            cube([rj45jackSize.x+rj45jackBottomExtraWidth, rj45jackSize.y, rj45jackBottomDepth]);
            
        translate([-rj45PinsSize.x/2,-rj45boardSize.y-rj45PinsExtraSize, -rj45boardSize.z-rj45PinsSize.z+0.01])
            color("grey")
            cube([rj45PinsSize.x, rj45PinsSize.y + rj45PinsExtraSize, rj45PinsSize.z]);
            
        }
        
        translate([rj45holeWidthDistance/2, rj45hole1FrontPosition])
            cylinder(100, d=rj45holeDiameter, center=true);
        translate([-rj45holeWidthDistance/2, rj45hole1FrontPosition])
            cylinder(100, d=rj45holeDiameter, center=true);
        translate([rj45holeWidthDistance/2, rj45hole2FrontPosition])
            cylinder(100, d=rj45holeDiameter, center=true);
        translate([-rj45holeWidthDistance/2, rj45hole2FrontPosition])
            cylinder(100, d=rj45holeDiameter, center=true);
    }
}

ttgo485Size = [35+tolerance, 81+tolerance];
ttgo485BoardThickness = 1.2;
ttgo485BoardTopMaxThickness = 3.3;
ttgo485BoardBottomMaxThickness = 2.5;

usbCSize = [7.4 + 10, 9.5+tolerance, 3.4+tolerance];
usbCPosY = 22-tolerance/2;
usbCPosX = 5.5;

connectorPins = 2.2;
connectorExtraLength = 3;

powerConnectorSize = [9, 9.2 + connectorExtraLength, 7.2];
powerConnectorPos = [9.5, 5 + connectorExtraLength, 0];

module ttgo485()
{    
    translate([-ttgo485Size.x/2, -ttgo485Size.y, -ttgo485BoardThickness])
        cube([ttgo485Size.x, ttgo485Size.y, ttgo485BoardThickness]);
        
    translate([-ttgo485Size.x/2 - powerConnectorSize.x + powerConnectorPos.x, -powerConnectorPos.y, powerConnectorPos.z])
        color("grey")
        minkowski()
        {
            union(){
                cube(powerConnectorSize);
                translate([0,0,-connectorPins - ttgo485BoardThickness])
                    cube([powerConnectorSize.x, powerConnectorPos.y, connectorPins + ttgo485BoardThickness]);
            }
            sphere(tolerance);
        }
    
    dataConnectorSize = [12.4, 9.2 + connectorExtraLength, 7.2];
    dataConnectorPos = [13.2, 5 + connectorExtraLength, 0];
    translate([ttgo485Size.x/2 - dataConnectorPos.x, -ttgo485Size.y - dataConnectorSize.y +dataConnectorPos.y, dataConnectorPos.z])
        color("grey")
        minkowski()
        {
            union(){
                cube(dataConnectorSize);
                translate([0,dataConnectorSize.y - dataConnectorPos.y,-connectorPins - ttgo485BoardThickness])
                    cube([dataConnectorSize.x, dataConnectorPos.y, connectorPins + ttgo485BoardThickness]);
            }
            sphere(tolerance);
        }
    
    translate([-ttgo485Size.x/2 + dataConnectorPos.x - dataConnectorSize.x, -ttgo485Size.y - dataConnectorSize.y +dataConnectorPos.y, dataConnectorPos.z])
        color("grey")
        minkowski()
        {
            union(){
                cube(dataConnectorSize);
                translate([0,dataConnectorSize.y - dataConnectorPos.y,-connectorPins - ttgo485BoardThickness])
                    cube([dataConnectorSize.x, dataConnectorPos.y, connectorPins + ttgo485BoardThickness]);
            }
            sphere(tolerance);
        }
    
    sdCutoutSize = [24, 44, 2.5];
    
    translate([-sdCutoutSize.x/2,-sdCutoutSize.y - 15,-sdCutoutSize.z-ttgo485BoardThickness])
        color("grey")
        cube(sdCutoutSize);
        
    translate([-ttgo485Size.x/2 - usbCSize.x + usbCPosX,-usbCSize.y + -usbCPosY, 0])
        color("grey")
        cube(usbCSize);
}

module cableGland(wallThickness){
    translate([0,0,wallThickness])
        cylinder(h=5,d=21.36,$fn=6);// inner hex nut
        
    screwHexHeight = 5;

    threadOuterLength = 16;
    threadInnerLength = 8.5;
    translate([0,0,-(screwHexHeight + threadOuterLength)])
        cylinder(h=threadInnerLength + screwHexHeight + threadOuterLength, d=12.8); // M12 thread
    translate([0,0,-screwHexHeight])
        cylinder(h=screwHexHeight,d=17.6,$fn=6); // screw hex
}

moduleDistance = 16;

boardPosZ = 2.5;

caseSize = [rj45boardSize.x, rj45boardSize.y + moduleDistance, 21.2];
caseThickness = 2;
module case()
{
    //ttgo485cutout
    
    rj45HolderWidth = 25;
    rj45HolderThickness = 6;
    
    
    difference()
    {
        union()
        {
            difference()
            {
            translate([-caseSize.x/2, 0, 0])
                minkowski()
                {
                    cube(caseSize);
                    sphere(caseThickness);
                }
            translate([-caseSize.x/2, 0, 0])
                cube([caseSize.x, caseSize.y, caseSize.z]);
            }
            translate([-rj45boardSize.x/2, caseSize.y - rj45HolderWidth, boardPosZ])
                cube([rj45HolderThickness, rj45HolderWidth, caseSize.z - boardPosZ]); // pcb holder
            translate([rj45boardSize.x/2 - rj45HolderThickness, caseSize.y - rj45HolderWidth, boardPosZ])
                cube([rj45HolderThickness, rj45HolderWidth, caseSize.z - boardPosZ]); // pcb holder
            translate([-caseSize.x/2, caseSize.y - rj45boardSize.y, 0])
                cube([caseSize.x, rj45boardSize.y, rj45boardSize.z + boardPosZ]); // part under pcb
            translate([-25/2, 0, 0])
                cube([25, 1.5, caseSize.z-2]); // holder for hex nut
        }

        translate([0, rj45boardSize.y + moduleDistance, boardPosZ + rj45boardSize.z])
            rj45breakout();
            
        translate([0,-caseThickness,caseSize.z/2])
            rotate([-90,0,0])
            cableGland(caseThickness);
    }

}

module diffPart()
{
    diffPartWidth = caseSize.x + caseThickness*2;
    diffPartLength = caseSize.y + caseThickness*2;
    
    innerEdge = 1.5;
    
    diffPartInnerWidth = caseSize.x + innerEdge;
    diffPartInnerLength = caseSize.y + innerEdge;
    
    translate([-diffPartWidth/2,-caseThickness,caseSize.z])
        cube([diffPartWidth, diffPartLength, 5]);
    
    translate([-diffPartInnerWidth/2,-innerEdge/2,caseSize.z - 2])
        cube([diffPartInnerWidth, diffPartInnerLength, 5]);
    
    translate([-caseSize.x/2,moduleDistance,boardPosZ + rj45boardSize.z])
        cube([caseSize.x, rj45boardSize.y, caseSize.z]);
}

if($preview){
    difference()
    {
        case();
        translate([-12, -5, caseSize.z - 5])
            cube(caseSize*2);
    }
    translate([50,0,0])
        color("red", 1)
        diffPart();
}

difference()
{
    case();
    diffPart();
}


translate([-60, 0, caseSize.z])
rotate([180,0,180])

intersection()
{
    case();
    diffPart();
}

//diffPart();

if($preview)
{
    translate([0, rj45boardSize.y + moduleDistance, boardPosZ + rj45boardSize.z])
        rj45breakout();
        
    translate([0,-caseThickness,caseSize.z/2])
        rotate([-90,0,0])
        cableGland(caseThickness);
    
    translate([40, 0, 0])
        rj45breakout();
    translate([80, 0, 0])
        ttgo485();
}

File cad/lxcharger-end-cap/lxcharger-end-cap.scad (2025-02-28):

$fn = $preview ? 16 : 64;

// for LXCHARGER H65AC

profileSize = [33.6, 15.5];
profileSizeInner = [29.2, 11.4];

module profileCorner(){
    polygon([
        [0, profileSize.y/2],
        [profileSizeInner.x/2, profileSize.y/2],
        [profileSize.x/2, profileSizeInner.y/2],
        [profileSize.x/2, 0],
        [0,0]
        ]);
}

module profile(){
    profileCorner();
    mirror([1,0])
        profileCorner();
    mirror([0,1]){
        profileCorner();
        mirror([1,0])
            profileCorner();
    }
}

module hole(holeDiameter, headDiameter, topDiameter, extraSink)
{
    cylinder(h=100, d=topDiameter);
    translate([0,0,-100])
    cylinder(h=100, d=holeDiameter);
    translate([0, 0, -((headDiameter-holeDiameter)/2*1.14)- extraSink])
        cylinder(h=(headDiameter-holeDiameter)/2*1.14, d1=holeDiameter, d2=headDiameter);
    translate([0, 0, -extraSink-0.01])
        cylinder(h=extraSink+0.02, d=headDiameter);
}

capDepth = 1.5;

holeYOffset = 0.3;
holeDistance = 30;
holeDiameter = 2.2;

xt30Size = [10, 5];
xt30Pos = [5.1, 3.1];
xt30Clearance = 0.3;

module cap(){
    difference()
    {
        linear_extrude(capDepth)
            profile();
        translate([holeDistance/2, holeYOffset, capDepth])
            hole(holeDiameter,3.2,holeDiameter,0.3);
        translate([-holeDistance/2, holeYOffset, capDepth])
            hole(holeDiameter,3.2,holeDiameter,0.3);
        translate([-profileSize.x/2 + xt30Pos.x, -profileSize.y/2 + xt30Pos.y, -0.01])
            minkowski(){
                cube([xt30Size.x, xt30Size.y, 5]);
                sphere(r=xt30Clearance);
            }
    }
}

cap();

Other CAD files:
cad/inverter-box/frontpanel/mount_sb120.stl
cad/inverter-box/frontpanel/din-rail-mount.stl
cad/esp-box/esp32-case.stl
cad/battery/battery-fpconnector-aux-power/battery-aux-power-mount.scad
cad/battery/battery-fpconnector-bus/battery-bus-mount.scad
cad/battery/battery-fpconnector-switch/battery-switch-mount.scad
cad/battery/battery-sb120-mount/battery-connector-mount.scad
cad/battery/bms-mount/bms-mount.scad
cad/esp-box/esp32-case.scad
cad/inverter-box/air-duct/Duct v16.f3d
cad/inverter-box/box/inverter-box.scad
cad/inverter-box/din-rail-plug/din-rail-plug.scad
cad/inverter-box/frontpanel/din-rail-mount.scad
cad/inverter-box/frontpanel/frontpanel.scad
cad/inverter-box/frontpanel/handle-filler.scad
cad/inverter-box/frontpanel/sbmount.scad
cad/inverter-box/mcb-mount/mcb-mount.scad
cad/inverter-box/top-holder/top-holder.scad
cad/inverter-box/top-holder/top-holder.stl

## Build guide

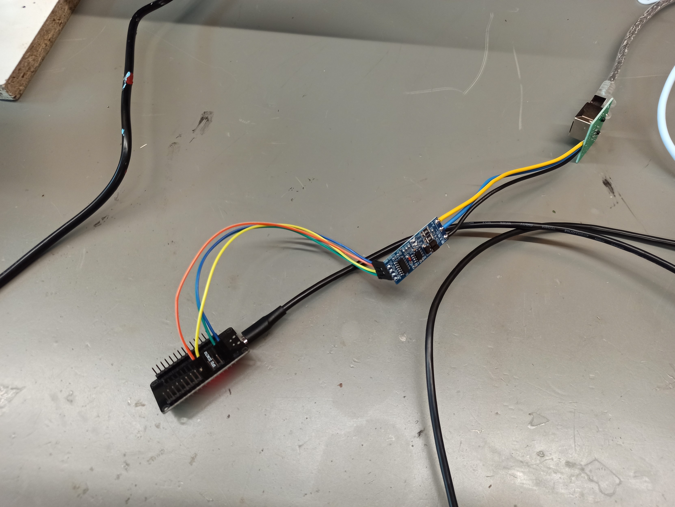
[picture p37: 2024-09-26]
img/03_inverter/03_inverter-readout-setup.jpg

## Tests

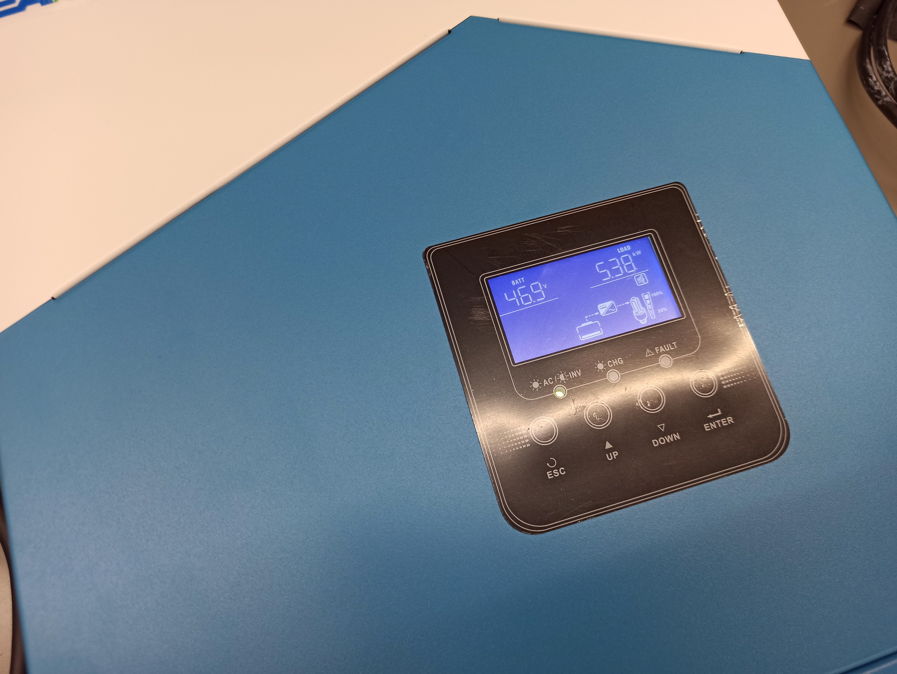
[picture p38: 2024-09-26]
img/03_inverter/02_inverter-load-test.jpg

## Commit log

2024-09-21 inverter-box: add inverter, din rail
    [inverter-box.scad]
2024-09-23 add front panel
    [frontpanel.scad]
2024-09-25 bms mounting plate
    [bms-mount.dxf, bms-mount.scad]
2024-09-28 add bms comm issues to readme
2025-01-02 add battery connector mount
    [battery-connector-mount.scad, battery-connector-mount.stl, plug-fill-adapter.scad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]
2025-01-06 adapt SB120 plug fill adapter for SB50
    [plug-fill-adapter.scad, plug-fill-adapter_sb120.stl, plug-fill-adapter_sb50.stl]
2025-01-06 add sb120, sb50, gnd to front panel
    [frontpanel.scad]
2025-01-06 increase tolerances
    [frontpanel.scad, mount_sb50.stl, plug-fill-adapter.scad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]
2025-01-09 add din rail mount
    [din-rail-mount.scad, din-rail-mount.stl]
2025-01-10 add din rail mount to front panel
    [din-rail-mount.scad, frontpanel.scad]
2025-01-11 put sb mount in separate file
    [frontpanel.scad, mount_sb120.stl, mount_sb50.stl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]
2025-01-11 change ground to m8 bolt
    [frontpanel.scad]
2025-01-11 add connector labels
    [frontpanel.scad]
2025-01-11 fix capitalization on front panel
    [frontpanel.scad]
2025-01-11 fix din rail zero coord
    [frontpanel.scad]
2025-01-11 add hole tolerances
    [frontpanel.scad, sbmount.scad]
2025-01-12 add front panel export files, update readme
    [frontpanel.scad]
2025-01-17 fix din rail, fix typo, change frontpanel pictures, add air duct
    [Duct v16.f3d, Duct.stl, din-rail-mount.scad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]
2025-01-17 add plug for din rail hole
    [din-rail-plug.scad, din-rail-plug.stl]
2025-01-19 add initial esp32 case version
    [esp32-case.scad]
2025-01-19 esp32 case: more tolerances everywhere
    [esp32-case.scad, esp32-case.stl]
2025-02-02 frontpanel: prepare for matching eurobox closer
    [frontpanel.scad]
2025-02-03 frontpanel: match eurobox closer
    [frontpanel.scad]
2025-02-06 fix frontpanel
    [frontpanel.scad]
2025-02-11 frontpanel: round edges more so they fit box better
    [frontpanel.scad]
2025-02-12 add top plate holder
    [top-holder.3mf, top-holder.scad, top-holder.stl]
2025-02-14 fix top holder countersink
    [top-holder.scad]
2025-02-27 add mcb sidewards mount
    [mcb-mount.scad, mcb-mount.stl]
2025-02-27 esp case v2
    [esp32-case-v2.scad, esp32-case-v2.stl]
2025-02-27 esp case v2.1
    [esp32-case-v2.scad, esp32-case-v2.stl]
2025-02-28 add RJ45 breakout case
    [rj45-case.scad, rj45-case.stl]
2025-02-28 esp case changelog
    [esp32-case-v2.scad]
2025-02-28 fix RJ45 case
    fix pcb holder pins floating
    derive board thickness from board size
    [rj45-case.scad, rj45-case.stl]
2025-02-28 add end cap for lxcharger
    [lxcharger-end-cap.scad, lxcharger-end-cap.stl]
2025-03-15 battery rs485 connector mount
    [battery-bus-mount.scad, battery-bus-mount.stl]
2025-04-01 battery aux power powerpole mount
    [battery-aux-power-mount.scad, battery-aux-power-mount.stl]
2025-04-01 update readme, add labeling to ESP case
    [esp32-case-v2.scad, esp32-case-v2.stl]
2025-04-07 add battery bus picture
2025-07-30 add touch protection shroud for box handle
    [handle-filler.scad, handle-filler.stl]
2025-09-03 readme: add sections about inverter EMF and BMS current measurment issues
2025-09-04 move cad files around
    [Duct v16.f3d, Duct.stl, battery-aux-power-mount.scad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]
2025-09-04 add battery front panel connector for switch
    [battery-switch-mount.scad, battery-switch-mount.stl]
